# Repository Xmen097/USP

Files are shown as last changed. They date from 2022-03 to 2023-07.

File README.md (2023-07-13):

# USP
Univerzální sériový programátor pro (převážně) AVR čipy.

### Popis
Hlavním cílem projektu bylo vytvořit hardwarový výrobek, který bude reálně užitečný a výraznězjednodušší nahrávání do (převážně) AVR čipů v pouzdře DIP, bez nutnosti zapojovat cokoliv na nepájivém poli. Programátor detekuje jaký čip je do něj vložený umožňuje ho programovat ze sériové linky. Na hardwarové úrovni bylo dále implementováno i několik bonusových funkcí, jako například podpora vysokonapěťového programování, které pouze čekají na implementaci v softwaru.

Sestavené ařízení bylo otestováno na několika mikrokontrolérech, konkrétně Atmega328 a Attiny13, Attiny85 a Attiny45.

Více informací v textu maturitní práce
https://github.com/Xmen097/USP/blob/master/Maturitn%C3%AD%20pr%C3%A1ce.pdf



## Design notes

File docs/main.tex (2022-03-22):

\documentclass[11pt,a4paper,twoside,openright]{report}

\usepackage[top=25mm,bottom=25mm,right=25mm,left=30mm,head=12.5mm,foot=12.5mm]{geometry}
\let\openright=\cleardoublepage

\input{macros}

\def\NazevPrace{Univerzální sériový programátor}
\def\Trida{R8.A}
\def\AutorPrace{Petr Šícho}
\def\DatumOdevzdani{25.3.2022}

% Vedoucí práce: Jméno a příjmení s~tituly
\def\Vedouci{Bc. Emil Miler}

% Studijní program a obor
\def\StudijniProgram{studijní program}
\def\StudijniObor{studijní obor}

% Text čestného prohlášení
\def\Prohlaseni{Prohlašuji, že jsem svou práci vypracoval samostatně a použil jsem pouze prameny a literaturu
uvedené v~seznamu bibliografických záznamů. Nemám žádné námitky proti zpřístupňování této práce v~souladu se
zákonem č. 121/2000 Sb. o~právu autorském, o~právech souvisejících s~právem autorským a
o~změně některých zákonů (autorský zákon) ve znění pozdějších předpisů.}

% Text poděkování
\def\Podekovani{%
Chtěl bych poděkovat především open hardware komunitě, specificky pak Arduino komunitě, na jejíchž fórech jsem našel značné množství informací. Dále děkuji Bc. Emilovi Milerovi za pomoc při vedení této maturitní práce.
}

% Abstrakt česky
\def\Abstrakt{%
Tato maturitní práce si klade za cíl zjednodušit proces programování a nahrávání kódu do mikrokontrolérů v pouzdře DIP. Univerzální sériový programátor (USP), který v rámci této práce vznikl, je zařízení, které je schopné automaticky detekovat rozložení vývodů čipu vloženého do ZIF patice. Na základě toho rozpozná o který mikrokontrolér se jedná a uzpůsobí pro něj nahrávací obvod. Teoreticky by měl USP umět programovat všechny mikrokontroléry pracující na napětí 5 voltů a podporovat dostatečně pomalé bit-banging programovací protokoly, včetně těch, které vyžadují vysoké napětí (12V) pro resetování. Aktuálně je implementována podpora rodin ATtiny a ATmega od výrobce Atmel. Na softwarové úrovni USP pracuje na protokolu Arduino ISP.
}

% Abstrakt anglicky
\def\AbstraktEN{%
This thesis aims to simplify the process of programming and uploading code to microcontrollers in a DIP package. The Universal Serial Programmer (USP), which was created in this work, is a device that is able to automatically detect the distribution of terminals on a chip inserted into the ZIF socket. Based on this, it recognizes which microcontroller is present and adapts the programming circuit for it. Theoretically, the USP should be able to program all microcontrollers operating at 5 volts and supporting sufficiently slow bit-banging programming protocols, including those that require high voltage (12V) for reset. A support is current implemented for the ATtiny and ATmega families from the manufacturer Atmel. At a software level, the USP is working on the Arduino ISP protocol. 
}

% 3 až 5 klíčových slov
\def\KlicovaSlova{programátor, mikrokontrolér, AVR, nahrávač, USP}
% 3 až 5 klíčových slov anglicky
\def\KlicovaSlovaEN{programmer, microcontroller, AVR, uploader, USP}

\begin{document}

\include{titlepage}

% Obsah
\setcounter{tocdepth}{2}
\tableofcontents

\chapter{Teoretická část}
\pagestyle{fancy}

Existuje nepřeberné množství různých čipů a s nimi podobné množství různých rozložení vývodů, které nejsou jednotné ani u jedné velikosti a jednoho výrobce. Pro každé rozložení pinů mikrokontroléru je nutné mít externí programovací obvod. Cílem práce je sjednotit tyto programovací obvody do jednoho univerzálního, který se přizpůsobí vloženému čipu. Fungování USP lze rozdělit na dvě části - detekovat čip a následně umožnit jeho programování. 

Pro univerzální programátor není možné použít žádný dedikovaný hardware, který by zajišťoval nahrávání. Naopak je vhodné použítí univerzálních vstupních~/~výstupních pinů neboli GPIO\footnote{z anglického General-purpose input/output, tedy pin, který se umí chovat buď jako digitální vstup, nebo výstup, přičemž mezi těmito módy je možné přepínat.} pinů. I přes snahu o maximální univerzálnost není reálné docílit podpory úplně všech existujících čipů. Jako minimální požadovanou funkcionalitu jsem tedy bral podporu čipů AVR od výrobce Atmel, konkrétně pak řady ATmegy a ATtiny, které zahrnují mikrokontroléry, jež pohání známé desky Arduino. Přesto se domnívám, že vlastnosti těchto čipů, na kterých je detekce a nahrávání postaveno, budou do velké míry přenositelné i na jiné rodiny či výrobce čipů.

\section{Detekce}

Základem detekce je poznat jak velký čip je - tedy kolik má vývodů. Tím bychom mohli v prvním přiblížení detekce radikálně omezit počet potenciálních kandidátů. Při zahrnutí jen několika modelů, jednoho pro každou velikost, bychom tak měli detekci téměř hotovou. Bylo by však nutné arbitrárně stanovit tyto podporované čipy, přičemž při vložení jiného, ať třeba ze stejné rodiny, který má prohozené piny GND a VCC, by došlo pravděpodobně k jeho zničení. Naší ambicí tedy bude zjistit o čipu co nejvíce informací, díky nimž budeme schopni rozeznávat mezi co největším počtem různých čipů.

Při detekci si musíme dávat pozor, abychom náhodou mikrokontrolér nepoškodili. Ideálně bychom se chtěli držet v hodnotách, které povoluje jeho datasheet. Problém je, že to, o co se pokoušíme, není standardní zacházení s čipy a v datasheetu tak nenalezneme konkrétní povolené hodnoty a situace, kterým můžeme čip bezpečně vystavit. Z datasheetu vybraných AVR čipů \cite{attiny85, atmega328, atmega2560, attiny84} můžeme alespoň určit některé společné zásady, kterých když se budeme držet, tak minimalizujeme poškození čipu. Konkrétně se jedná o:
\begin{itemize}
	\item Nevystavovat žádný pin napětí nižšímu než $-0.5V$
	\item Nevystavovat žádný pin, kromě RESETu, napětí vyššímu než ${V}_{cc} + 0.5V$
	\item Nevystavovat RESET napětí vyššímu než $13V$
	\item Nenechat mezi žádný dvěma piny nezapojeného čipu téct nezanedbatelně velký proud po nezanedbatelně dlouhou dobu\footnote{Pro naše účely budeme považovat za zanedbatelný proud řádu mikroampér a čas mikrosekund.}
\end{itemize}
Při splnění těchto podmínek by měl být čip dostatečně chráněn obvody, které běžně slouží k ochraně před elektrostatickým výbojem (ESD). 

\subsection {Detekce velikosti a polohy \label{theory:capacitance}}

Pro detekci velikosti čipu můžeme využít toho, že každá reálná součástka, kromě svých primárních vlastností, vykazuje také elektrickou kapacitu. To bude jistě platit i pro spoje a součástky uvnitř integrovaných obvodů. Elektrická kapacita pinů jednoduchých CMOS\footnote{Complementary metal-oxide semiconductor; technologie výroby integrovaných obvodů.} čipů \cite{multiplexer, switch2, switch1} se pohybuje v jednotách pikofaradů. Není mi znám žádný způsob přímého měření elektrické kapacity, budeme tedy muset provést měření nepřímé a dostatečně přesné. Jednou z možností je kapacitor pomalu nabíjet nebo vybíjet a měřit čas, který k tomu budeme potřebovat. Zkusíme odhadnout jak přesné takové měření bude s pomocí rovnice definující energii elektrického kondenzátoru \begin{equation} E = \frac{1}{2}CU^2 \end{equation}
Budeme-li kapacitor nabíjet napětím $U$ a proudem $I$ po dobu $t$, můžeme psát
\begin{equation} {W}_{max} = U \cdot I \cdot t \end{equation} 
Jedná se o horní odhad vykonané práce, která počítá s nulovým odporem a nulovým elektrickým potenciálem kapacitoru. Reálná energie předaná kapacitoru bude nižší, což nám však nevadí. Úpravou těchto dvou vztahů můžeme vyvodit úměrnost
\begin{equation} C \simeq t / R \end{equation}

Zjistili jsme, že kapacita je přímo úměrná času, po který jsme kapacitor nabíjeli, a nepřímo úměrná odporu, přes který jsme nabíjeli.\footnote{Ke stejnému výsledku bychom došli i použitím rozměrové analýzy.} Čas budeme schopni měřit velice přesně\footnote{Přesnost měření času je omezena frekvencí oscilátoru řídícího mikrokontroléru, běžně se pohybuje v desítkách megahertzů.}, řádově v mikrosekundnách ($10^{-6} s $). Řekněme, že pin čipu má kapacitu $10 pF = 10^{-11} F$. Dosazením do vztahu (1.3) zjistíme, že k jejímu změření budeme potřebovat nabíjecí odpor o velikosti $100 k\Omega$. To nebude problém, měření vypadá proveditelně.

Díky schopnosti změřit kapacitu na každém z pinů socketu zjistíme nejenom jak velký čip je, ale zároveň i kde v socketu je vložen. Není tedy nutné nijak specifikovat na jakou pozici v socketu má být čip pro nahrávání vložen.

\subsection {Detekce speciálních pinů}

Každý mikrokontrolér má kromě vstupních~/~výstupních pinů i speciální piny, které plní nějakou zvláštní funkci. Například je to RESET pin, napájecí piny (GND a VCC) nebo piny hodin (XTAL). Tyto piny by mohly vykazovat rozdílné elektrické vlastnosti a možná i rozdílnou kapacitu. Vzhledem k tomu, že napájecí piny jsou vnitřně připojené k všemožným součástem mikrokontroléru, lze hlavně u těchto pinů očekávat vyšší kapacitu. Tu bychom při dostatečně přesném měření kapacity detekovat a rozpoznat tak polohu napájecích pinů.

\subsection {Rozpoznání VCC od GND\label{VCCvsGND}}

Při špatném rozpoznání vloženého mikrokontroléru může největší poškození způsobit převrácení pinů GND a VCC. Abychom se tohoto rizika vyvarovali, je nutné rozpoznávat s jistotou VCC od GND. Tím zároveň obecně snížíme šanci na špatné rozpoznání čipu.

Využijeme ochranných diod, které jsou připojeny ke každému IO pinu mikrokontroléru, jak ukazuje obrázek \ref{fig:pin_diagram}. Povšimněme si, že dioda spojující pin s GND směřuje opačně, než dioda spojující pin s VCC. Díky tomu bychom měli být schopni rozpoznat, zda je určitý pin GND či VCC.

\begin{figure}[ht!]
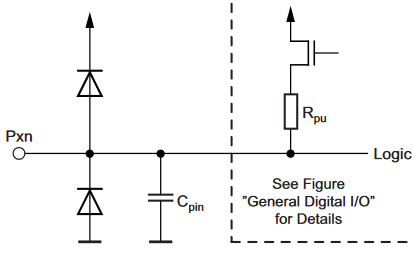
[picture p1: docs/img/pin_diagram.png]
  
  \centering
  \caption{Schéma vnitřního zapojení IO pinu mikrokontroléru \cite[str.~58]{atmega328}.}
  \label{fig:pin_diagram}
\end{figure}

Pin GND můžeme detekovat následovně. Budeme znát úbytek napětí na diodě mezi pinem a GND $U_d$. Přivedeme-li na pin GND napětí $U$ převyšující $U_d$, měli bychom na všech IO pinech detekovat napětí $U-U_d$. Z bezpečnostních důvodů by napětí $U$ by mělo být co nejmenší možné, ideálně $U<0.5V$. Napětí přivedeme přes dostatečně velký odpor tak, aby mikrokontrolérem a diodou tekl co nejmenší proud. S malým procházejícím proudem budeme mít také menší úbytek napětí na diodě (menší, než běžně udávaných $\sim0.7V$)

Obdobným způsobem je možné detekovat pin VCC. Stačí na libovolný (nebo lépe postupně na všechny) IO pin přivést napětí $U$ a na pinu VCC by se nám vždy mělo ukázat napětí $U-U_d$.

\subsection {Závěr}

S touto výbavou bychom měli být schopni dostatečně detailně rozpoznat mikrokontroléry ATmega a ATtiny. Díky rozpoznáním GND a VCC budeme schopni čip bezpečně napájet. Nebude pak problém, kdybychom chtěli rozšířit podporované čipy a vyskytly by se nám dva čipy, které mají na stejných místech GND a VCC, ale na různých místech piny potřebné pro nahrávání. V této situaci bychom postupně vyzkoušeli různá rozložení nahrávacích pinů, až bychom našli to správné.

\section {Nahrávání}

Po detekování čipu nám už zbývá pouze do něj nahrát. Vzhledem k tomu, že přesně nevíme jaké rozložení pinů bude čip mít, musíme použít tzv. bit-banging\footnote{Softwarová implementace určitého protokolu, která přímo generuje protokolem specifikovaný signál, bez použití specializovaného hardwaru.}. Díky tomu se nemusíme při stavbě hardwaru nahrávače omezovat na určité čipy, ale budeme schopni teoreticky obsluhovat všechny čipy, které nevyžadují příliš velké komunikační rychlosti\footnote{Maximální rychlost komunikace je tím, jak rychle jsme schopni zpracovávat odchozí a příchozí data.} a existuje pro ně bit-banging implementace nahrávání. Nebude tak ani obtížné obměňovat nahrávací protokoly pro různé čipy nebo situace.

Komplikací může být, že některé nahrávací protokoly vyžadují použití vyššího napětí. U AVR čipů jde konkrétně o protokoly HVSP (high voltage serial programming) a HVPP (high voltage parallel programming), které se hodí při určitém nastavení mikrokontroléru, kdy není možné standardní programování.\footnote{Jde např. o situace kdy je vypnuté resetování pomocí RESET pinu, protože ho chceme použít na jinou funkci.} Vysokým napětím je v obou případech myšleno 12 voltů \cite{AVRprog}. Vzhledem k tomu, že ve valné většině případů lze programovat mikrokontrolér bez použití vysokého napětí, bral jsem jeho dostupnost spíše jako bonus než nutný požadavek. High-voltage programováním se tedy budeme zabývat pouze z hardwarového hlediska.

\section {Shrnutí požadovaných funkcí\label{pinFunc}}

V této sekci si shrneme funkce, které budeme potřebovat pro úspěšnou detekci a nahrávání do čipů. Těmito funkcemi by měl disponovat každý z pinů socketu, neboť nevíme, kde se zrovna čip ocitne. Některé funkce budou komplexní (přečti kapacitu připojenou k pinu), u jiných se bude jednat o nějaký elementární stav (připojení k zemi/5V). 

\begin{enumerate}
\item \textbf{5V s proudem >20 mA} je potřeba pro napájení čipu. Proud 20 mA by měl stačit pro napájení AVR čipů \cite{attiny85, atmega328}. Některé větší čipy za určitých okolností mohou mít spotřebu větší než 20 mA, ale mají také více separátních napájecích pinů, mezi které se proud rozloží \cite[str.~286-323]{atmega32}.
\item \textbf{0V (GND) s proudem >20 mA} je potřeba též pro napájení čipu. 
\item \textbf{5V s libovolně malým proudem} reprezentuje logický stav 1 při komunikaci, odebíraný proud během komunikace bude zanedbatelný.
\item \textbf{0V (GND) s libovolně malým proudem} reprezentuje logický stav 0 při komunikaci.
\item \textbf{Čtení digitální hodnoty} pro čtení odpovědi čipu při nahrávání; standardní funkce GPIO pinů.
\item \textbf{Přečtení kapacity} pro detekci čipu.
\item \textbf{Napětí přibližně 0.4-0.5V} je potřeba pro rozpoznání GND a VCC, viz sekce \ref{VCCvsGND}.
\item \textbf{Přečtení napětí na pinu} je také potřeba pro rozpoznání GND a VCC.
\item \textbf{12V} bude potřeba pokud budeme chtít high-voltage programování.
\item \textbf{Nepřipojeno} k ničemu. Piny, které nevyužíváme k jiné funkci, by se měly chovat tak, jako kdyby nebyly k ničemu připojené.
\end{enumerate}

%%% IMPLEMENTACE

\chapter{Implementace}

Implementace projektu měla dvě fáze. Nejprve bylo potřeba navrhnout hardwarovou část - vymyslet a vyzkoušet jednotlivé části obvodu tak, aby plnily požadované funkce. Poté bylo potřeba všechny spojit do jednoho celku, který se vyrobí jako plošný spoj. Po osazení plošného spoje součástkami a otestování základní funkčnosti následoval vývoj softwaru. Jako první probíhala implementace low-level komunikace s jednotlivými součástkami, pak přišly na řadu high-level funkce detekce. 

Pojďme si nyní jednotlivé fáze rozebrat detailněji.

\section {Hardware}

Převážná část práce na hardwaru probíhala s pomocí nepájivého pole, na kterém jsem postupně testoval jednotlivé ideje uvedené v teoretické části práce. V následujících sekcích si rozebereme jaké součástky byly použity a jak se pomocí nich implementují požadované funkce ze sekce \ref{pinFunc}.

\subsection {Vkládání čipu}

Jako patici, do které se bude vkládat čip k programování, jsem zvolil ZIF (zero insertion force) socket. Jak již jméno napovídá, pro vložení čipu do patice není nutné užití síly. Stačí čip položit na patici a pomocí páčky na straně patice čip zajistit, čímž vznikne spolehlivý kontakt s piny čipu. Nehrozí tak ohnutí nožiček čipu a jeho vložení i vyndání je velmi rychlé. Nevýhodou ZIF socketu je o trochu vyšší pořizovací cena a větší velikost, ale i přesto se v našem případě určitě vyplatí. Konkrétně jsem zvolil patici se 40 piny (dvaceti na každé straně), která by měla postačovat pro naprostou většinu DIP\footnote{Dual in-line package; pouzdro s THT piny s roztečí 2.54mm.} pouzder. Patice podporuje vložení jak úzké (0.3''), tak široké (0.6'') varianty DIP.

\subsection {Řídící mikroprocesor}

Je potřeba zvolit mikroprocesor, který bude ovládat celý nahrávač. Volil jsem mezi mikrokontroléry AVR, s kterými jsem nejvíce obeznámen a které také umí jednoduše komunikovat s Arduino IDE. Zásadní otázkou je kolik budeme potřebovat GPIO pinů k ovládání USP. Určitě bude potřeba jeden pin pro každý pin ZIF patice, tedy minimálně 40 pinů. Další desítky pinů budou potřeba pro ovládaní komponent a součástek, o kterých se budu detailněji zmiňovat v dalších sekcích. Teoreticky by bylo možné přidat další piny pomocí shift registrerů či IO expanderů. Tím by však utrpěla rychlost komunikace a vzrostla by komplexita desky a tím i prostor pro chyby. Rozhodl jsem se tedy pro jeden co největší čip, mikrokontrolér ATmega2560 v pozdře TQFP100, který má 84 GPIO pinů \cite{atmega2560}.

Nejprve jsem plánoval, že bych využil dostupných schémat Arduino desek a v upravené podobě je přímo zakomponoval do desky nahrávače. To by umožnilo využít řídící čip bez omezení. Na druhou stranu by tím extrémně vzrostla komplexita desky a také celková cena. Nakonec jsem se tedy rozhodl programátor vyvinout jako shield (nasazovací desku) na Arduino Mega s mikroprocesorem ATmega2560. Nevýhodou tohoto postupu může být snad jen to, že Arduino mega nám dává k dispozici pouze 70 z 84 GPIO pinů, ale i to by mělo pro tento projekt stačit \cite{ArduinoMega}.

\subsection {Základní funkcionalita pinů}

Nyní přichází na řadu implementace požadovaných funkcí popsaných v sekci \ref{pinFunc}. Jenom tím, že ke každému pinu ZIF socketu bude připojený GPIO pin, zajistíme funkce 3, 4, 5, které GPIO piny zvládají nativně. Funkce 1 a 2, které vyžadují minimální proud 20 mA, také s trochou opatrnosti zvládneme. Digitální piny ATmegy2560 dokáží dodávat maximální proud 40 mA \cite[str.~355-356]{atmega2560}. Musíme tedy jen dát pozor na to, aby další součástky, které budou zapojeny mezi GPIO pinem a pinem ZIF socketu neměly příliš velký odpor nebo nevyžadovaly více omezený protékající proud.

Desátý požadavek vyžaduje trochu zamyšlení. Pin určitě nebude možné fyzicky odpojit, to bychom museli provést manuálně. Budeme tedy alespoň chtít minimalizovat proud, který může skrz tento \lq odpojený\rq   pin téct. Když nastavíme GPIO pin jako vstupní, bude ve stavu s tzv. vysokou impedancí, tedy poteče jím malý proud. Datasheet specifikuje maximální proud jako $1 \mu  A$, typický proud lze očekávat výrazně menší \cite[str.~355]{atmega2560}. Odpojení si navíc můžeme pojistit použitím analogového přepínače, u kterého je udáván maximální proud $100nA$ a typický $0.05nA$ \cite[str.~3]{switch1}.

\subsection {Zapojení multiplexerů}

Implementaci funkcí 6, 7, 8 a 9 si zjednodušíme pozorováním, že v jednu chvíli bude daná funkce potřebná pouze na jednom pinu. Nemusíme ji tedy implementovat 40x, ale můžeme použít multiplexery k spojení určitého pinu s něčím, co nám funkci zajistí. Napětí na pinu budeme číst pomocí ADC\footnote{Analogově digitální převodník; zařízení, které převede analogový signál (napětí) v určitém rozsahu na digitální tvar s určitým počtem bitů, v našem případě se jedná o převodník 10-bitový.} převodníku. Atmega2560 disponuje jedním ADC převodníkem, který je ale vnitřně multiplexován na 16 GPIO pinů. Pomocí dalších multiplexerů rozšíříme tuto funkcionalitu na všech 40 pinů.

%Pro zajištění správného přečtení napětí nemůžeme nechat ADC převodník tzv. floating, tedy nepřipojený k ničemu, kdy vrací víceméně náhodné hodnoty. Všech 5 ADC pinů, které využíváme, je tedy připojeno rezistorem $1M\Omega$ k zemi. Takto vysokou hodnotu rezistoru jsem volil, aby se nezkreslily výsledky měření kapacity.

Multiplexery se standardně vyrábí s $2^n$ kanály, které se ovládají pomocí $n$ pinů. Zvolil jsem 8 kanálové multiplexery \cite{multiplexer}, tedy s 3 ovládacími piny. Pro obsluhu 40 pinů jich bude potřeba celkem 5. Multiplexery jsou připojeny k pinům ZIF socketu způsobem znázorněným na obrázku \ref{fig:mux_diagram}.

\begin{figure}[ht!]
  
  \centering
  \caption{Schéma zapojení mulitplexerů k pinům ZIF patice.}
  \label{fig:mux_diagram}
\end{figure}

Díky tomuto způsobu zapojení budeme schopni odhalit závadu na multiplexeru při rozpoznávání čipu, neboť i nejmenší mikrokontrolér, který má pouzdro DIP8 se 4 piny na každé straně, bude mít vždycky alespoň dva piny v různých multiplexerech. Nestane se tedy, že by kvůli závadě na jednom multiplexeru (ta může být způsobená i třeba dotekem uživatele, kterým se zvýší kapacita) byl čip chybně rozpoznán.

\subsection {Napěťový dělič \label{voltage_divider}}

Napětí 0.4-0.5V, jak si žádá sedmý požadavek, vytvoříme pomocí napěťového děliče. Zde se nám budou hodit již výše zmíněné multiplexery. Dělič napětí bude totiž právě mezi GPIO pinem a multiplexovaným pinem. Na každém GPIO pinu je možné zapnout tzv. pullup rezistor, který pin připojí přes odpor s přibližnou velikostí $30-40k\Omega$\footnote{Datasheet udává, že odpor bude vždy větší než $20k\Omega$ a menší než $50k\Omega$. Vzhledem k tomu, že tyto hodnoty jsou pro teplotní rozmezí od -55°C do 125°C můžeme konstatovat, že při pokojové teplotě bude odpor přibližně mezi $30-40k\Omega$.} k 5 voltům. Kýžené napětí přibližně půl voltu vytvoříme dalším rezistorem s velikostí $3.3k\Omega$\footnote{Chceme dělič napětí přibližně 1:10, hodnotu odporu jsem zvolil o něco nižší, protože i samotný multiplexer bude mít určitý odpor (asi 100 ohmů).} k zemi. Zapojení děliče napětí na pinu je vidět na obrázku \ref{fig:voltage_divider}

\begin{figure}[ht!]
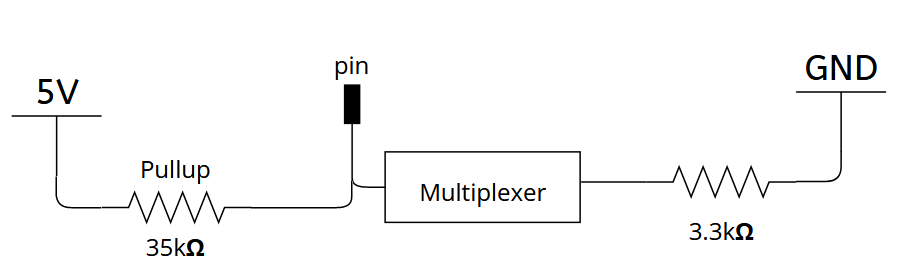
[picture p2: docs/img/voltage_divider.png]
  
  \centering
  \caption{Schéma děliče napětí.}
  \label{fig:voltage_divider}
\end{figure}

\subsection{Měření kapacity}

Kapacitu lze měřit, jak jsme vyvodili v sekci \ref{theory:capacitance}, pomocí pomalého nabíjení - tedy nabíjení přes dostatečně velký rezistor. Vypočítali jsme, že by se nám hodil rezistor s odporem $100k\Omega$. Připojovat takový odpor k pinům by si však vyžádalo dalších multiplexerů nebo switchů. Můžeme ale využít stejných pullup rezistorů, které využíváme pro napěťový dělič. Ty jsou o něco menší a mohlo by se stát, že kapacitor nabijeme příliš rychle. Můžeme ale využít ADC převodníku, který máme multiplexovaný k pinům. Původně jsme chtěli měřit čas, za který nabijeme plně kapacitor, což bychom zjišťovali pomocí digitálního vstupu GPIO pinů. Můžeme to ale provést i opačně. Kapacitor budeme nabíjet nějaký konstantní čas, a poté pomocí ADC převodníku zjistíme napětí na kapacitoru. Čím vyšší napětí bude, tím více jsme kapacitor nabili a tím je tedy kapacitor menší. Opačně by šlo i kapacitor plně nabít a poté ho nechat samovolně vybíjet. Počkáme konstantní čas a opět pomocí ADC převodníku zjistíme, jak moc se vybil. 

Při testování se ukázalo, že pro měření kapacity se nám velmi hodí i dělič napětí, podrobněji viz sekce \ref{software:capacitance}

\subsection {Napětí 12 voltů\label{12v}}

Poslední funkcionalitou, kterou nám zbývá implementovat je dostupnost napětí 12 voltů. To můžeme na pin pouštět pomocí stejných multiplexerů, které využíváme k připojení ADC převodníku. Stačí pomocí switche CD4066B \cite{switch2} přepínat zdroj multiplexeru mezi 12 volty a ADC převodníkem. Zapojení tohoto obvodu pro multiplexer 1 a 2 je vyobrazeno v příloze  \ref{appendix:mux_input_control}. Od použitého switche nepožadujeme žádné zvýšené nároky ohledně proudu, pro HVSP i HVPP nám stačí malý proud. Problém je, že náš řídící mikrokontrolér, ale ani většina dobře dostupných multiplexerů, nepodporuje vyšší napětí než 5 voltů. S trochou snahy se dají najít i multiplexery podporující 12 voltů. Řídíci čip, jehož piny odolají napětí 12 voltů, ale prakticky není možné najít. Budeme proto muset piny řídíciho mikrokontroléru odpojit předtím, než připojíme 12 voltů. K tomu využijeme analogové switche MC14066B \cite{switch1}. Vzhledem k tomu, že přes tyto switche budeme mimo jiné napájet čip, který budeme chtít programovat, musí podporovat průtok proudu alespoň $20mA$.\footnote{Z tohoto důvodu se použitý switch liší od switchů \cite{switch2}, které používáme u zdroje multiplexeru.} 

Každý switch má 4 kanály, které dokáže přepínat pomocí 4 ovládacích pinů. Není však možné ani potřebné ovládat každý z těchto pinů individuálně, na to bychom totiž spotřebovali dalších 40 pinů. Šlo by pomocí tranzistorů a odporů detekovat zvýšené napětí a přepnout ovládací pin switche. To by však vyžadovalo značné množstí externích komponent - na každý pin jeden tranzistor a několik odporů. Lepší řešení je založené na faktu, že 12 voltů bude vždy připojené na pinu, který je multiplexován. Toho využijeme a přidáme další multiplexer, který bude mít stejně zapojené ovládací piny jako první multiplexer. Bude fungovat tak, že vypne kanál, který obsluhuje pin, ke kterému je multiplexováno. Tímto zajistíme přepínání s použitím pouze jediného pinu, který bude sloužit k potlačení této funkcionality, která by nám rozbila napětový dělič a další funkce. Zjednodušené schéma tohoto systému pro 8 pinů ZIF patice je znázorněno na obrázku \ref{fig:simplified_pin_switches}. Tento obvod je na USP celkem 5 krát - pro každých 8 pinů, a to podle stejné schématu jako zapojení původních multiplexerů (obrázek \ref{fig:mux_diagram}). Kompletní zapojení toho obvodu je dostupné jako příloha \ref{appendix:pin_switches}.

\begin{figure}[ht!]
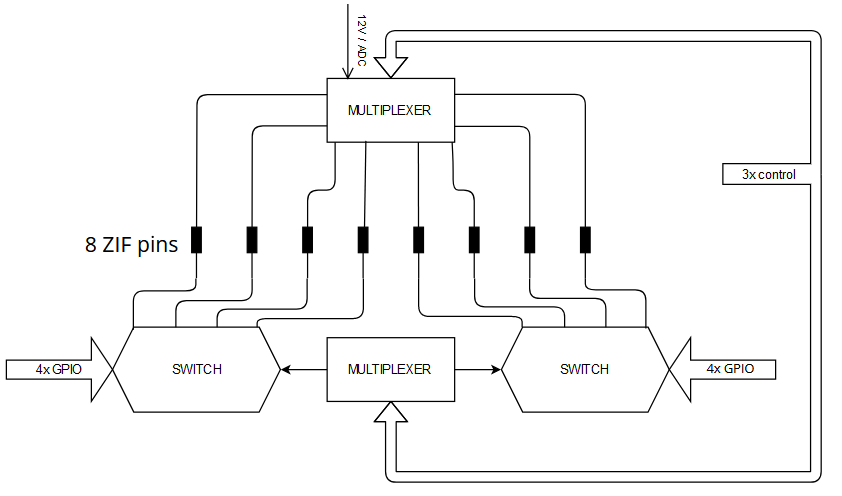
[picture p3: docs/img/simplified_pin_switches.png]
  
  \centering
  \caption{Zjednodušené schéma obvodu připojeného k 8 pinům ZIF patice}
  \label{fig:simplified_pin_switches}
\end{figure}

Další komplikací spojenou s vyšším napětím je, že multiplexery a switche potřebují být ovládané tímto napětím. Nestačí tedy již připojit na ovládací pin multiplexeru/switche GPIO pin řídícího mikrokontroléru, ale je nutné použít tranzistor a pullup/pulldown\footnote{V závislosti na tom v jakém výchozím stavu chceme, aby byl ovládací pin; ve většině případu se bude jednat o pulldown rezistor.} rezistor.

Poslední věcí, kterou musíme vyřešit, je kde získat napětí 12 voltů. Jednou možností by bylo zapojit do USP přímo toto napětí z externího zdroje, to by ale výrazně ztížilo jeho použití. Rozhodl jsem se proto přímo do USP zabudovat step-up převodník, který nám vytvoří napětí 12V. Obvod step-up převodníku byl navržen podle datasheetu regulátoru MC34063A \cite{step-up}. Celé zapojení obvodu převodníku je zobrazeno v příloze \ref{appendix:boost_converter}.

\subsection {Dodatečný hardware}

Krom výše uvedených součástek a obvodů, které slouží k zajištění detekce nebo nahrávání, je USP vybaven také 0.91'' OLED displejem a čtyřmi tlačítky. To umožní tvorbu uživatelského rozhraní pro jednodušší ovládání programátoru. OLED displej je také užitečným nástrojem pro debugování. Dále jsou pak na programátoru tři LED - modrá, zelená a červená, které slouží pro optickou signalizaci stavu programátoru.

\subsection {Využití pinů}

Nakonec se ukázalo, že 70 pinů není až zase tolik a bylo nutné s nimi trochu šetřit. Následovat bude krátký přehled toho, k čemu bylo použito kolik pinů a případně jakým způsobem byly piny uspořeny.

\begin {itemize}
\item \textbf{40 pinů} je nutných k obsloužení všech pinů na ZIF patici.
\item \textbf{5 pinů s podporou ADC} je připojeno k pěti multiplexerům.
\item \textbf{3 piny} jsou použity pro sdílenou kontrolu multiplexerů na právé straně ZIF patice (1, 2 a 3). \footnotemark{}
\item \textbf{3 piny} jsou použity pro sdílenou kontrolu multiplexerů na levé straně ZIF patice (4 a 5). \footnotemark[\value{footnote}]
\item \textbf{5 pinů} ovládá jestli je každý z pěti multiplexerů připojen k 12 voltům nebo ADC převodníku.
\item \textbf{1 pin} ovládá zda switche odpojují piny, na které je právě multiplexováno, jak je popsáno v sekci \ref{12v}.
\footnotetext{Pro všechny funkce kromě rozpoznání VCC a GND (sekce \ref{VCCvsGND}) nám stačí vždy jen jeden pin připojený k multiplexeru, ostatní multiplexery můžeme ignorovat. Pro rozpoznání VCC a GND budeme potřebovat dva multiplexery, jeden pro vytvoření malého napětí a druhý pro čtení ostatních pinů. K tomu nám ale postačí nezávisle ovládat multiplexery na jiných stranách ZIF patice, neboť díky rozložení multiplexerů podle obrázku \ref{fig:mux_diagram} bude mít i nejmenší možný čip alespoň dva piny na různých stranách.}
\item \textbf{2 piny} jsou použity pro display.
\item \textbf{4 piny} jsou využívány tlačítky.
\item \textbf{3 piny} ovládají LEDky.
\item \textbf{2 piny} jsou potřeba pro sériovou komunikaci s počítačem.
\item \textbf{zbylé 2 piny} jsou vyvedeny do headeru.
\end {itemize}

Celkem je tedy využito všech 70 dostupných pinů.

\subsection {Plošný spoj}

Po otestování částí některých výše zmíněných obvodů na nepájivém poli bylo potřeba vytvořit návrh desky plošného spoje. Rozhodl jsem se rovnou pro 4-vrstvý plošný spoj, vzhledem k tomu, že jsem plánoval umístit co nejvíce součástek na co nejmenší plochu a vrchní vrstva je tak prakticky celá pokryta ploškami pro kontakty součástek. Prostřední dvě vrstvy jsou udělány jako tzv. plane, kde většina vrstvy zabírá jeden signál, zde konkrétně země a napájení, a slouží pro snížení rušení na desce. Hotového zapojení plošného spoje je k nahlédnutí v příloze \ref{appendix:board}.

%Plošný jsou jsem si nechal vyrobit a osadit SMD součástkami u nejmenované čínské firmy. Hlavní výhodou objednání z Číny je řádově menší cena, než u ostatních výrobců, problémem na druhou stranu může být, že čínané mají často vlastní kopie součástek a jejich datasheety nejsou přeložené do angličtiny. Většinou jsou k nalezení anglické datasheety prakticky totožných součástek jiných výrobců. Po výrobení plošného spoje jsem začal zjišťovat na co vše jsem při návrhu zapomenul a co nefunguje. Naštěstí nic z toho nebylo kritické a bylo možné všechny nedostatky opravit.

%%% SOFTWARE

\pagebreak
\section {Software}

Přestože bylo cílem projektu vytvořit co nejlepší hardwarový výrobek, je jeho nedílnou součástí i software nutný k zprovoznění tohoto hardwaru. Nicméně ne všechny funkce implementované na hardwarové úrovni jsou využity ze strany softwaru. 

\subsection{Princip fungování}

Po zapnutí USP detekuje vložení čipu, který následně identifikuje a data o něm předá nahrávači (více o něm v sekci \ref{software:uploader}). Nahrávač pak vykonává příkazy, které dostane po sériové lince a programuje vložený čip, dokud uživatel nezmáčkne resetovací tlačítko. Princip fungování konkrétně zachycuje obrázek \ref{fig:app_diagram}. 

\begin{figure}[ht!]
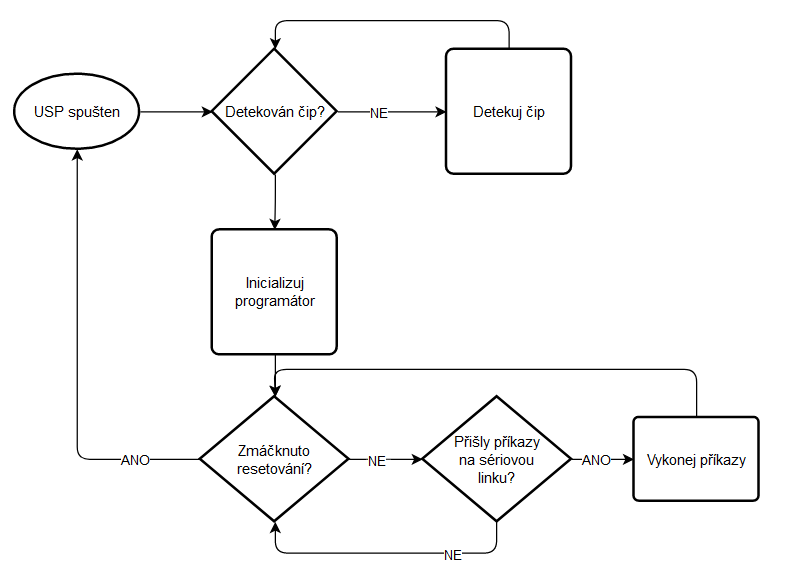
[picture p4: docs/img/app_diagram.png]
  
  \centering
  \caption{Diagram USP}
  \label{fig:app_diagram}
\end{figure}

\subsection {Nízkoúrovňové funkce}

Jako první bylo potřeba implementovat funkce pro ovládání hardwaru - konkrétně multiplexerů, OLED displeje a tlačítek. U tlačítek stačilo implementovat tzv. debouncing, tedy brát tlačítko jako stisknuté až tehdy, když se jeho stav po nějakou dobu nemění.

Pro práci s displejem jsem použil knihovnu od Adafruitu pro ovladač SSD1306, kterým je displej vybaven. Pro převod obrázků a grafik na displej jsem využil aplikaci image2cpp \cite{image2cpp}. Na displeji jsou implementovány převážně debugovací funkce, které se však mohou hodit i během provozu zařízení. Není totiž vyloučené, že měření, která bylo potřeba nakalibrovat\footnote{Měření kapacity je kalibrované pomocí aditivní a multiplikativní konstanty, které byly nalezeny experimentálně. Bez těchto úprav se kapacita na pinech výrazně lišila, pravděpodobně z důvodu rozdílné délky spojů na PCB, případně jejich vystavení působení jiných komponent.}, se budou v určitých situacích chovat trochu jinak a bude nutné je kalibrovat znovu. Z tohoto důvodu jsou kalibrační data uložena v paměti EEPROM, aby je bylo možné měnit i bez flashování.

Pro zprovoznění multiplexerů jsem použil návrhový vzor Composite, kdy každý z pěti multiplexerů je instancí třídy, která obstarává vnitřní mapování jeho ovládacích pinů na výstup a další nastavení. Všechny multiplexery jsou pak společně ovládány pomocí jiné třídy, která pozná, který multiplexer má použít.

\subsection {Interface \label{software:capacitance}}

Interface funguje jako prostředník mezi nízkoúrovňovými hardwarovými funkcemi a detektorem, kterým se bude zabývat následující sekce. Poskytuje funkce změření kapacity či napětí na pinu, připojení napětí 0.5 voltu a další.

Měření kapacity bylo implementování s přesností, která umožňuje rozpoznání polohy speciálních pinů. Prakticky měření probíhá tak, že pin nabíjíme pomocí napětí 0.5 voltů po dobu 5 mikrosekund\footnote{Tato doba při testování dávala nejlepší výsledky.}. Pak nabíjet přestaneme a změříme napětí, které na pinu je. Samotné změření napětí trvá nějaký čas, během kterého se pin stihne částečně vybít. Změřené napětí je tedy zčásti dáno rychlostí nabíjení i rychlostí vybíjení. Tento způsob měření ukázal, že piny GND a VCC mají prakticky dvojnásobnou měrnou kapacitu než normální piny. Pin RESET je také zajímavý. U některých čipů se z pohledu kapacity chová jako kdyby tam vůbec nebyl. U jiných čipů má naopak kapacitu výrazně vyšší než normální piny. V obou situacích jsme schopni pin RESET rozpoznat jako speciální pin.

\subsection {Detektor}

Detektor implementuje vysokoúrovňovou detekci čipů. Jeho fungování je znázorněno na obrázku \ref{fig:detector}. 

\begin{figure}
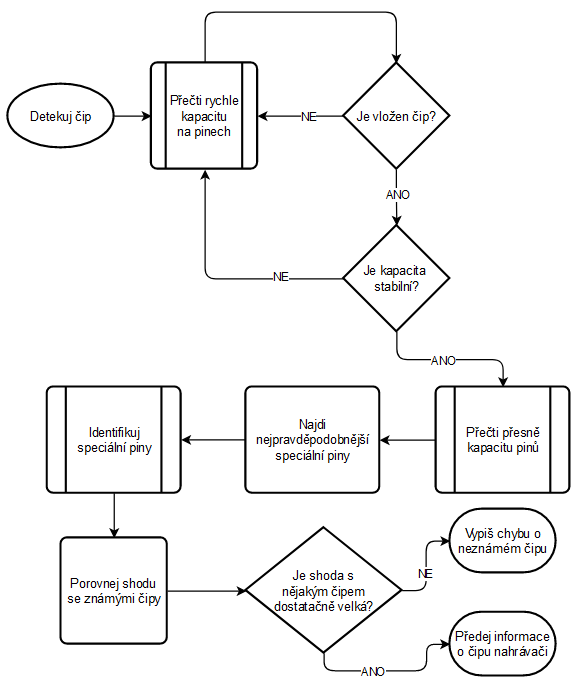
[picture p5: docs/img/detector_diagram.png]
  
  \centering
  \caption{Diagram fungování detektoru. Dvojité obdélníky značí funkce, které interagují s hardwarem}
  \label{fig:detector}
\end{figure}

Jednou z důležitých funkcí je detekce speciálních pinů. Pro každý pin vloženého čipu vyčíslíme, jak moc se relativně odlišuje od průměrné kapacity pinů na daném čipu. Toto číslo budeme přeneseně brát jako pravděpodobnost, že pin je speciálním pinem. Pět pinů\footnote{Nejvyšší počet speciálních pinů, který může AR čip o maximální podporované velikosti, je 5, včetně RESETu, ale teoreticky ani čip s více speciálními piny nebude problém detekovat, neboť i s pomocí pěti pinů bychom ho měli s jistotou určit.} s největší pravděpodobností vybereme a budeme je dále identifikovat, jak zachycuje obrázek \ref{fig:detect_special}.
Vzhledem k zjištěním při měření kapacity popsaných v sekci \ref{software:capacitance} by se mělo jednat, s danou pravděpodobností, o některý ze speciálních pinů - tedy buď GND, VCC nebo RESET.

\begin{figure}
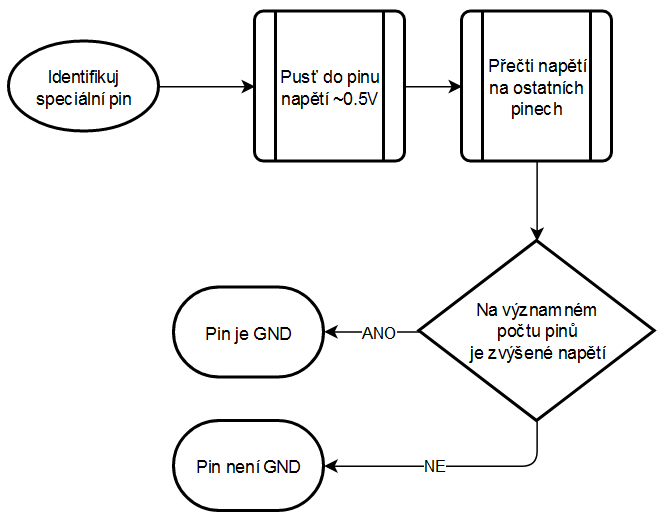
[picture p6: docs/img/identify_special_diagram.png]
  
  \centering
  \caption{Diagram identifikace speciálních pinů}
  \label{fig:detect_special}
\end{figure}

Cílem identifikace je rozpoznat, jestli je speciální pin GND. Ke pět nejpravděpodobnějším speciálním pinům, které jsme vybrali, si doplníme informaci jestli jsou pinem GND. Pokud pin není GND, jedná se buď o VCC, RESET, nebo o pin, který byl chybně detekován jako speciální (v takovém případě by jeho pravděpodobnost, a tedy i vliv na výslednou volbu čipu, měla být minimální).

Nakonec budeme iterovat přes všechny podporované čipy dané velikosti a pro obě možná otočení čipu zjistíme, jestli jeho speciální piny sedí se speciálními piny, které jsme detekovali. Výsledná shoda čipu je součet pravděpodobností těchto shodných speciálních pinů. Nejpravděpodobnější čip, který překonal stanovenou minimální shodu, je prohlášen za identifikovaný a informace o něm jsou předány dále.

\subsection {Nahrávač \label{software:uploader}}

Díky detektoru teď víme, jaký čip je vložen do patice, na jaké je pozici a jak je orientovaný. Víme tedy také, kde jsou umístěny piny, které potřebujeme pro nahrávání. Tyto informace již tedy stačí předat nahrávači. Pro zjednodušení jsem využil již implementovaný nahrávač, Arduino ISP, který je distribuovaný s Arduino IDE. Tento nahrávač jsem zvolil mimo jiné proto, že ho lze snadno ovládat právě z Arduino IDE a při použití USP uživatelem tedy nebude nutné nic instalovat ani upravovat.

Do Arduino ISP jsem doimplementoval softwarový oscilátor pomocí hardwarového časovače zabudovaného v čipu ATmega2560 \cite{atmega2560}. Díky tomu je možné programovat i čipy, které vyžadují externí oscilátor.

Implementace nahrávače je udělaná tak, aby ho v případě potřeby bylo možné snadno vyměnit za jiný. To bude nutné třeba pro přidání podpory HVSP či HVPP, neboť tyto protokoly Arduino ISP nepodporuje.

\chapter{Technická dokumentace}

\section {Použití}

Univerzální sériový programátor nevyžaduje instalaci žádného dalšího programu pro použití. Z vnějšího pohledu se chová stejně jako standardní Arduino ISP, které je široce podporované. Po zapojení do počítače přes USB type-B port, kterým je Arduino Mega vybaveno, může chvíli (několik sekund) trvat, než se USP inicializuje a zahájí komunikaci s počítačem přes sériový port\footnote{Ke komunikaci je nutné mít ovladače, ty se ale nainstalují samy při instalaci Arduina IDE, AVRDUDE nebo podobných programů.}. Poté, co se na obrazovce USP objeví nápis \lq Ready\rq ,  je USP připraven k vložení čipu. Ten může být vložen s libovolnou orientací a na libovolné místo. Aktuální verze USP podporuje prakticky všechny čipy řad Atmega a ATtiny v provedení DIP.\footnote{Fyzicky jsem však testoval jen dva různé čipy ATtiny a jeden ATmega, takže je možné, že pro určité specifické čipy bude potřeba upravit parametry v kódu a ten flashovat do USP, více o tom v sekci \ref{selfupload}.} 

Ihned po vložení čipu a jeho zajištění páčkou probíhá detekování. Během tohoto procesu se programátoru nedotýkejte, mohlo by to způsobit špatnou detekci čipu. Po detekování se na displeji ukáže jméno detekovaného čipu.\footnote{Jméno na displeji se může lišit od reálného použitého čipu, neboť existuje mnoho variant čipů se stejným rozložením. Na displeji je zobrazeno jméno nejznámnějšího čipu s daným rozložením nebo čipu s největší pamětí.} V této chvíli je již možné do čipu nahrávat stejným způsobem jako do normálního zařízení Arduino ISP. Možné způsoby nahrávání do čipů přes USP si rozebereme v následujích sekcích.

Po vyndání čipu je možné stiskem libovolného tlačítka resetovat USP do původního stavu a připravit ho na další čip, který je možné vložit poté, co se na displeji objeví \lq Ready\rq .

\subsection {Použití s Arduino IDE}

Použití s Arduino IDE je pravděpodobně nejjednodušší. Jako příklad řekněme, že chceme nahrát program do čipu Atmega328P, který mimo jiné pohání Arduino Uno. Prvním krokem je zvolit Arduino ISP jako programátor pod Nástroje>Programátor>Arduino as ISP a zvolit Port do kterého je USP připojen. V nabídce portů se bude USP ukazovat pod jménem Arduino Mega. Dalším krokem je zvolit čip, do kterého budeme nahrávat v Nástroje>Vývojová deska. V našem příkladě to bude \lq Arduino Uno\rq , pod čímž se skrývá čip Atmega328 nastavený na použití externího oscilátoru s frekvencí 16Mhz, který je na desce Arduino Uno. Toto nastavení, se zvýrazněnými důležitými parametry, je na obrázku \ref{fig:uno_settings}.

\begin{figure}[ht!]
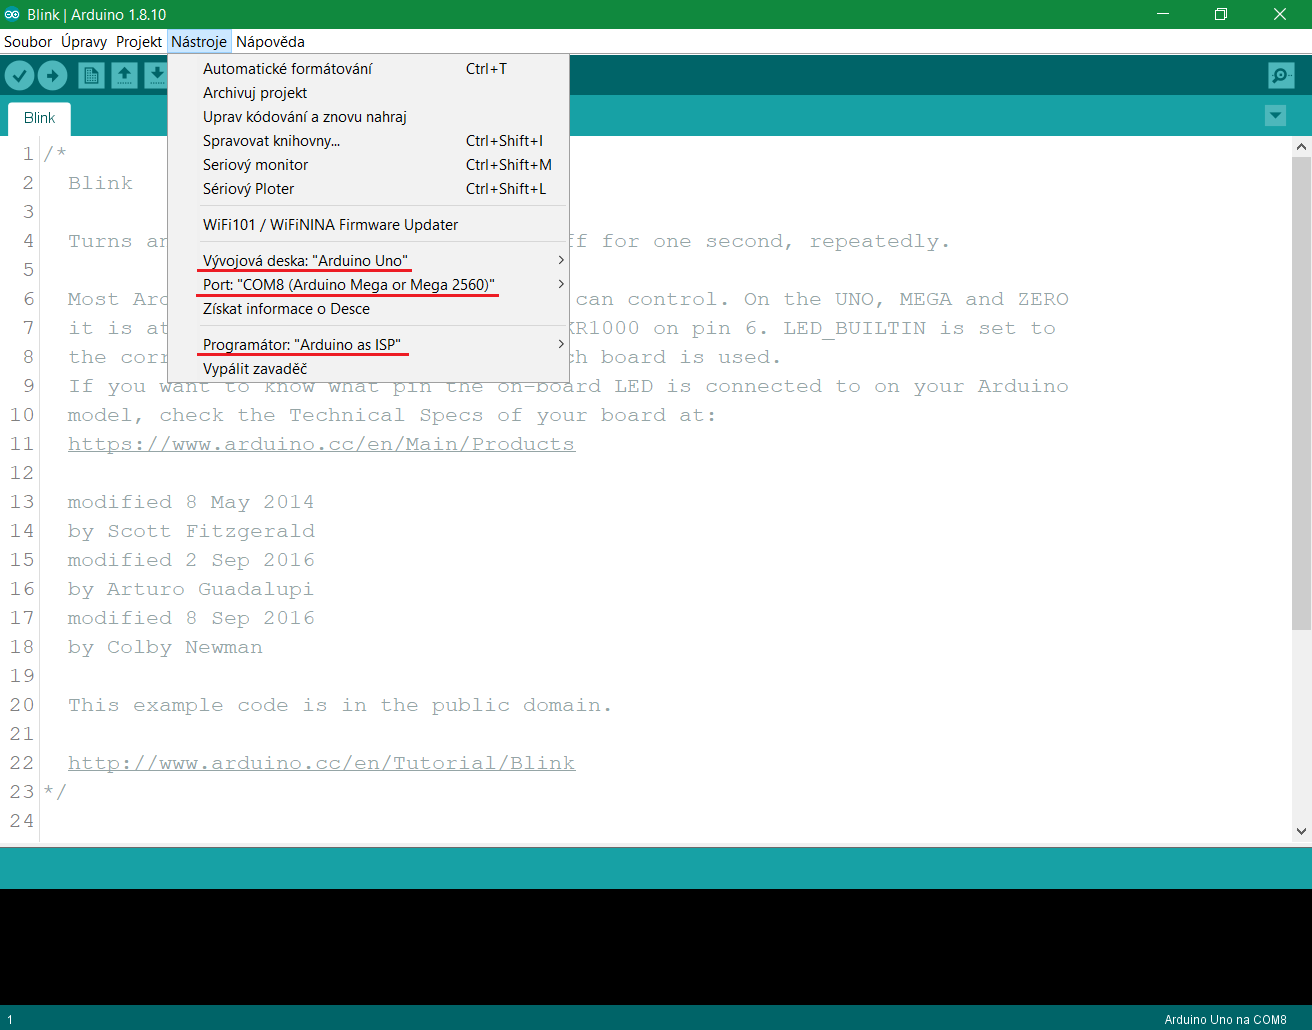
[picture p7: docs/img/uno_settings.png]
  
  \centering
  \caption{Nastavení Arduino IDE pro nahrávání do čipu ATmega328 s externím oscilátorem 16Mhz; zvýrazněny jsou nejdůležitější parametry.}
  \label{fig:uno_settings}
\end{figure}

Nahrávání do jiných mikrokontrolérů, kterými nejsou obsazeny desky Arduino, vyžaduje stažení příslušných knihoven. Pro čipy ATtiny může být použita například knihovna ATTinyCore \cite{attinycore}. Po jejím nainstalování se nám příslušné mikrokontroléry ukáží pod Nástroje>Vývojová deska a bude pro ně dostupné více nastavení. Možná nastavení, která nemusí být dostupná pro každý mikrokontrolér, jsou BOD (Brown-out detection; napětí, při kterém se čip vypně), číslování pinů, hodiny (vnitřní/vnější oscilátor a jeho frekvence) a mnoho dalšího. Příklad nastavení pro programování čipu ATtiny84 s interním oscilátorem 8Mhz je na obrázku \ref{fig:attiny84_settings}.

\begin{figure}[ht!]
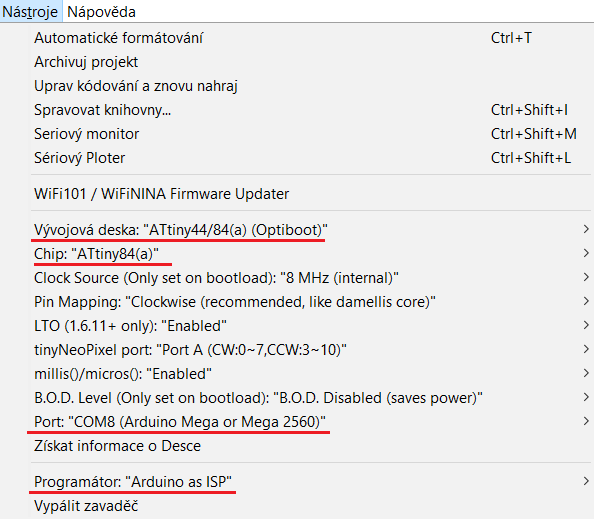
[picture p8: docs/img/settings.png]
  
  \centering
  \caption{Nastavení Arduino IDE pro nahrávání do čipu ATtiny84; zvýrazněny jsou nejdůležitější parametry.}
  \label{fig:attiny84_settings}
\end{figure}

V případě, že je toto první nahrávání do konkrétního čipu bude potřeba vypálit bootloader. To lze v Arduino IDE udělat pod Nástroje>Vypálit zavaděč. Tím se příslušné parametry, jako frekvence oscilátoru či BOD, vypálí do mikrokontroléru. Poté je již možné nahrávat program do čipu pod Projekt>Nahrát pomocí programátoru nebo pomocí zkratky Ctrl+Shift+U. 

Mikrokontrolér, do kterého jsme nahrávali kód pomocí programátoru, nebude následně možné programovat pomocí sériového portu. Tento způsob programování je využíván například při bězném nahrávání do desek Arduino Uno. Pokud tedy chceme čip vložit do desky Arduino Uno nebo podobné, bude nutné znovu vypálit bootloader pod Nástroje>Vypálit zavaděč. Poté již do čipu nenahrávejte s pomocí USP a vložte jej do desky Arduino Uno.

\subsection {Použití s AVRDUDE}

\begin{figure}[ht!]
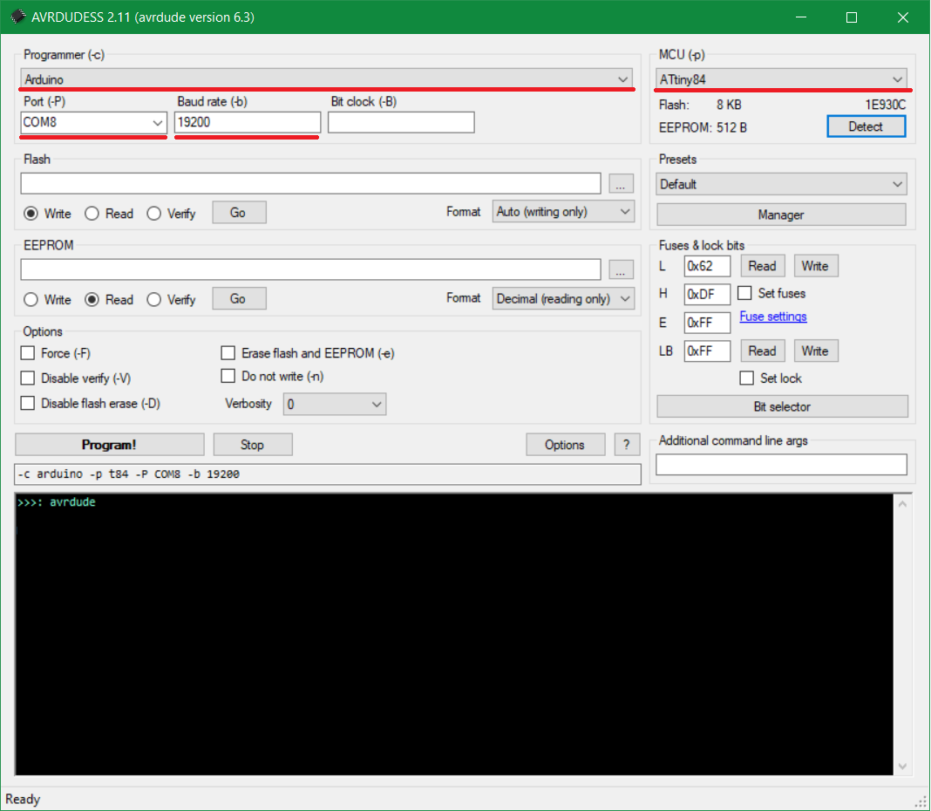
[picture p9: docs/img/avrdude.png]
  
  \centering
  \caption{Nastavení AVRDUDESS pro nahrávání do čipu Attiny84, zvýrazněny jsou nejdůležitější parametry.}
  \label{fig:avrdude}
\end{figure}

Podobně jako s Arduino IDE, lze nahrávat i programem AVRDUDE, případně s použitím UI verze zvané AVRDUDESS. Opět je nutné pouze zvolit port, programátor Arduino, cílový čip a tentokrát i rychlost komunikace 19200 baudů. Nastavení pro ATtiny84 je dostupné na obrázku \ref{fig:avrdude}. Hlavní výhodou AVRDUDE je, že pomocí něj jsme schopni nastavovat a číst fuse bits, číst a zapisovat do EEPROM či flash paměti či nastavovat lock bits. Lze pomocí něj do určité míry oživovat i zdánlivě mrtvé čipy.

\section {Nahrávání od USP \label{selfupload}}

Deska USP chrání řídící mikroprocesor na Arduino Mega proti nechtěnému flashování. V případě, že bude potřeba do něj nahrávat, je nutné nejdříve odstranit žlutý jumper s označením \lq self prog\rq , který se nachází na druhé straně desky než displej a tlačítka. Poté bude již možné nahrávat do Arduino Mega standardním způsobem.

\chapter*{Závěr}
\pagestyle{empty}
\addcontentsline{toc}{chapter}{Závěr}

Hlavním cílem projektu bylo vytvořit hardwarový výrobek, který bude reálně užitečný a výrazně zjednodušší nahrávání do (převážně) AVR čipů v pouzdře DIP. Tento cíl projekt splnil. Na hardwarové úrovni bylo implementováno i několik bonusových funkcí, jako například podpora vysokonapěťového programování, které pouze čekají na implementaci v softwaru.

Zařízení je funkční a bylo otestováno na několika mikrokontrolérech, které jsem měl k dispozici. Jeho spolehlivost by bylo možné dále zvýšit důkladnějším testování na dalších čipech a doladěním parametrů detekce. Také by bylo možné vytvořit uživatelsky přívětivé rozhraní, které by umožňovalo například volbu nahrávacího protokolu, případně poskytovalo některé funkce i bez připojení k počítači, k čemuž je také připraven potřebný hardware.

Během práce na projektu jsem se toho mnoho naučil nejen o AVR čipech a CMOS obvodech, které jsem využíval, ale také o elektrotechnice obecně. Získal jsem cenné zkušeností při návrhu plošného spoje, výběru potřebných komponent a zkoumání jejich vzájemných interakcí.  

%%% Seznam použité literatury
\printbibliography[title={Seznam použité literatury},heading={bibintoc}]

%%% Seznam obrázků
\openright
\listoffigures
\addcontentsline{toc}{chapter}{Seznam obrázků}

%%% Přílohy k práci, existují-li. Každá příloha musí být alespoň jednou
%%% odkazována z vlastního textu práce. Přílohy se číslují.

\part*{Přílohy}
\appendix

\renewcommand{\thefigure}{A.\arabic{figure}}

\setcounter{figure}{0}

\begin{figure}[ht!]
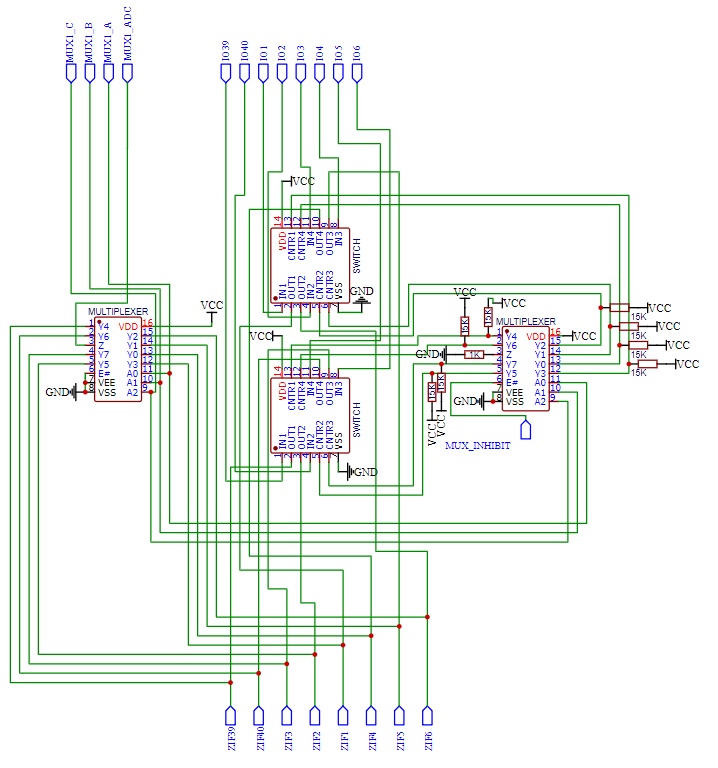
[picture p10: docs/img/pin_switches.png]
  
  \centering
  \caption{Úplné schéma obvodu připojeného k 8 pinům ZIF patice.}
  \label{appendix:pin_switches}
\end{figure}

\begin{figure}[ht!]
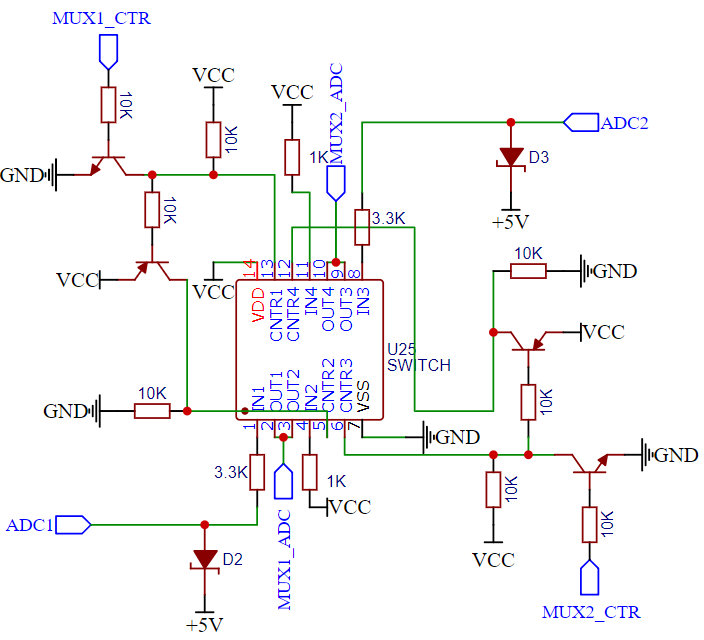
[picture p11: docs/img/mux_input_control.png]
  
  \centering
  \caption{Úplné schéma zapojení switche, který přepíná vstup do multiplexerů 1 a 2 mezi ADC pinem a 12V.}
  \label{appendix:mux_input_control}
\end{figure}

\begin{figure}[ht!]
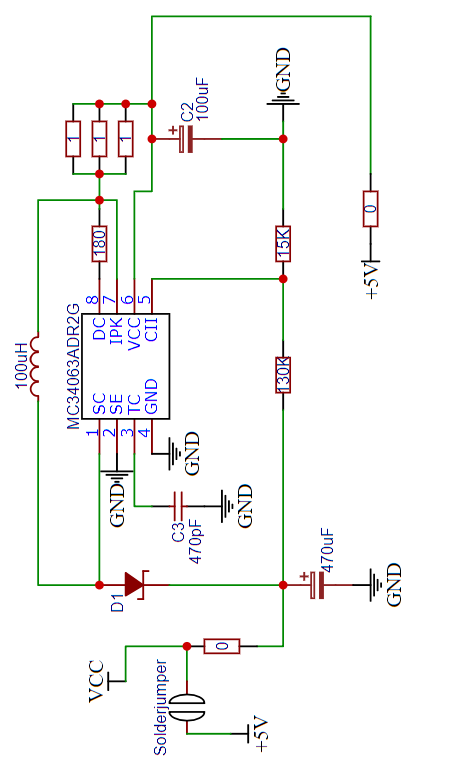
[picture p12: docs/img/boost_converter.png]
  
  \centering
  \caption{Úplné schéma obvodu step-up převodníku z 5 na 12 voltů. Obvod zahrnuje nula ohmové odpory a solder jumper, které umožňují jednoduché odpojení převodníku.}
  \label{appendix:boost_converter}
\end{figure}

\begin{figure}[ht!]
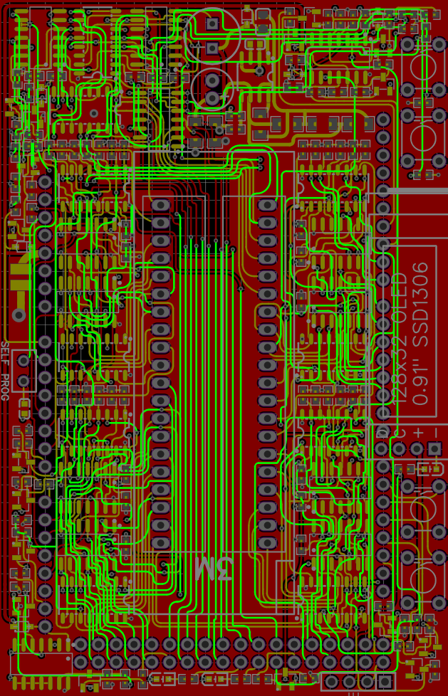
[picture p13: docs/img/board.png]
  
  \centering
  \caption{Zapojení plošného spoje. Žlutou barvou jsou vyznačeny spoje ve vrchní vrstvě, zelenou spoje spodní vrstvy a červenou spoje jedné z vnitřních vrstev. Druhá vnitřní vrstva není na obrázku zachycena.}
  \label{appendix:board}
\end{figure}

\end{document}

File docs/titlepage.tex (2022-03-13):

%%% Titulní strana práce a další povinné informační strany

%%% Titulní strana práce

\pagestyle{empty}
\pagenumbering{gobble}
\hypersetup{pageanchor=false}

\begin{center}
\LARGE
\textbf{GYMNASIUM JANA KEPLERA}\\
{\large Parléřova 2/118, 169 00 Praha 6}

\vspace{\stretch{3}}

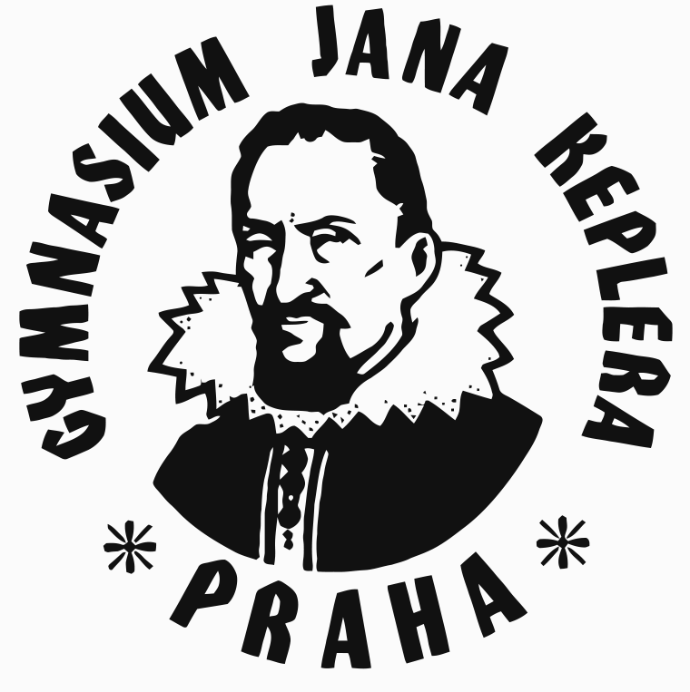
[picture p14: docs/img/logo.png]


\vspace{\stretch{3}}

{\Huge\bfseries\NazevPrace}

\vspace{8mm}
\mdseries{Maturitní práce}

\vspace{\stretch{8}}
\large
\begin{tabular}{rl}
Autor: & \AutorPrace \\
\noalign{\vspace{2mm}}
Třída: & \Trida\\
\noalign{\vspace{2mm}}
Školní rok: & 2021/2022\\
\noalign{\vspace{2mm}}
Předmět: & Informatika \\
\noalign{\vspace{2mm}}
Vedoucí práce: & \Vedouci \\
\end{tabular}

\vspace{20mm}
Praha, \DatumOdevzdani
\end{center}

\openright

\includepdf[]{zadani.pdf}

%%% Strana s čestným prohlášením k bakalářské práci

\hypersetup{pageanchor=true}
\cleardoublepage
\vspace*{\fill}
\section*{Prohlášení}
\noindent
\Prohlaseni

\vspace{2cm}
\noindent
V Praze dne \today
\hspace*{\fill}\small{\AutorPrace}
\vspace{1cm}

%%% Poděkování
\openright
\vspace*{\fill}
\section*{Poděkování}
\noindent
\Podekovani
\vspace{1cm}

%%% Povinná informační strana bakalářské práce
\openright
\section*{Abstrakt}
\noindent
\Abstrakt
\subsection*{Klíčová slova}
\noindent
\KlicovaSlova

\vfill

\section*{Abstract}
\noindent
\AbstraktEN
\subsection*{Keywords}
\noindent
\KlicovaSlovaEN

\openright
\pagenumbering{arabic}

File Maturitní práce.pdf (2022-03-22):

# GYMNASIUM JANA KEPLERA

### Parléˇrova 2/118, 169 00 Praha 6

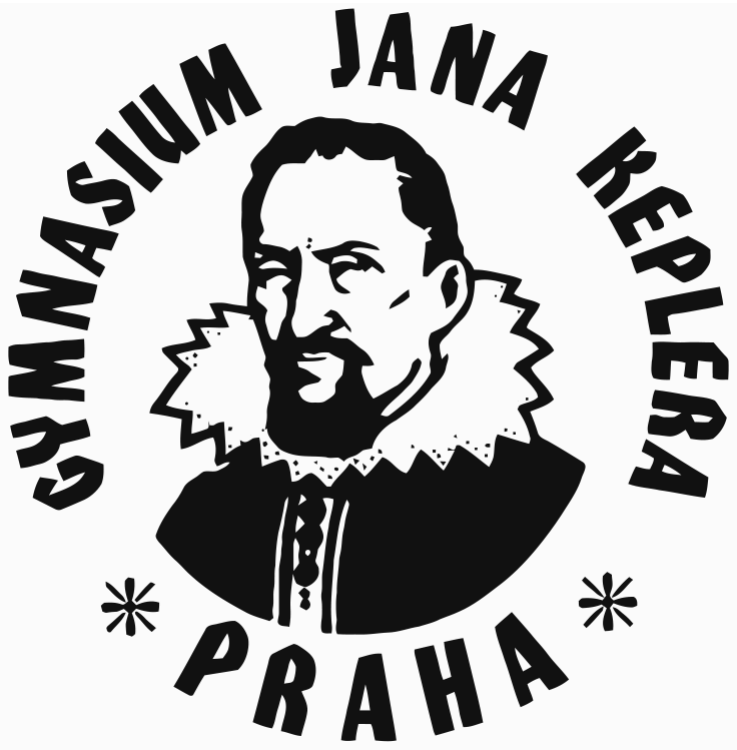
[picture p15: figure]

# Univerzální sériový programátor

# Maturitní práce

### Autor: Petr Šícho

### Tˇrída: R8.A

### Školní rok: 2021/2022

### Pˇredmˇet: Informatika

### Vedoucí práce: Bc. Emil Miler

### Praha, 25.3.2022

# GYMNASIUM JANA KEPLERA Kabinet informatiky

# ZADÁNÍ MATURITNÍ PRÁCE

Student: | Petr Šícho
Tˇrída: | R8.A
Školní rok: | 2021/2022
Platnost zadání: | 30. 9. 2022
Vedoucí práce: | Bc. Emil Miller
Název práce: | Univerzální sériový programátor

Pokyny pro vypracování: Cílem práce je vymyslet a vytvoˇrit univerzální programátor minimálnˇe pro nejznámnˇejší ˇcipy AVR, tedy ˇrady Attiny a Atmega. Univerzální programátor má ulehˇcit nahrávání do zmínˇených ˇcip ˚u, bez nutnosti zapojovat cokoliv na nepájivém poli. Programátor by mˇel detekovat jaký je do nˇej vložený ˇcip a umožnit do nˇej nahrávat z poˇcítaˇce. Za dodateˇcné, vedlejší, funkce by se dalo napˇríklad považovat možnost nahrávat do ˇcip ˚u pˇres pin header, tedy bez vyndavání ˇcipu z postaveného obvodu. Výsledkem projektu by minimálnˇe mˇel být funkˇcní

prototyp programátoru, který je použitelný pro specifikovaný úˇcel.

## Doporuˇcená literatura:

## URL repozitáˇre:

## https://github.com/Xmen097/USP

student | vedoucí práce

## V Praze dne 22. 10. 2021

# Prohlášení

Prohlašuji, že jsem svou práci vypracoval samostatnˇe a použil jsem pouze prameny a literaturu uvedené v seznamu bibliografických záznam ˚u. Nemám žádné námitky proti zpˇrístupˇnování této práce v souladu se zákonem ˇc. 121/2000 Sb. o právu autorském, o právech souvisejících s právem autorským a o zmˇenˇe nˇekterých zákon ˚u (autorský zákon) ve znˇení pozdˇejších pˇredpis ˚u.

V Praze dne 22. bˇrezna 2022 | Petr Šícho

# Podˇekování

Chtˇel bych podˇekovat pˇredevším open hardware komunitˇe, specificky pak Arduino komunitˇe, na jejíchž fórech jsem našel znaˇcné množství informací. Dále dˇekuji Bc. Emilovi Milerovi za pomoc pˇri vedení této maturitní práce.

# Abstrakt

Tato maturitní práce si klade za cíl zjednodušit proces programování a nahrávání kódu do mikrokontrolér ˚u v pouzdˇre DIP. Univerzální sériový programátor (USP), který v rámci této práce vznikl, je zaˇrízení, které je schopné automaticky detekovat rozložení vývod ˚u ˇcipu vloženého do ZIF patice. Na základˇe toho rozpozná o který mikrokontrolér se jedná a uzp ˚usobí pro nˇej nahrávací obvod. Teoreticky by mˇel USP umˇet programovat všechny mikrokontroléry pracující na napˇetí 5 volt ˚u a podporovat dostateˇcnˇe pomalé bit-banging programovací protokoly, vˇcetnˇe tˇech, které vyžadují vysoké napˇetí (12V) pro resetování. Aktuálnˇe je implementována podpora rodin ATtiny a ATmega od výrobce Atmel. Na softwarové úrovni USP pracuje na protokolu Arduino ISP.

## Klíˇcová slova

programátor, mikrokontrolér, AVR, nahrávaˇc, USP

# Abstract

This thesis aims to simplify the process of programming and uploading code to microcontrollers in a DIP package. The Universal Serial Programmer (USP), which was created in this work, is a device that is able to automatically detect the distribution of terminals on a chip inserted into the ZIF socket. Based on this, it recognizes which microcontroller is present and adapts the programming circuit for it. Theoretically, the USP should be able to program all microcontrollers operating at 5 volts and supporting sufficiently slow bit-banging programming protocols, including those that require high voltage (12V) for reset. A support is current implemented for the ATtiny and ATmega families from the manufacturer Atmel. At a software level, the USP is working on the Arduino ISP protocol.

## Keywords

programmer, microcontroller, AVR, uploader, USP

# Obsah

1 Teoretická ˇcást | 3
2 Implementace | 7
2.1.2 | Rídící mikroprocesor | ˇ | 7
3 Technická dokumentace | 17
Závˇer | 21
Seznam použité literatury | 23
Seznam obrázk ˚u | 25

# 1. Teoretická ˇcást

Existuje nepˇreberné množství r ˚uzných ˇcip ˚u a s nimi podobné množství r ˚uzných rozložení vývod ˚u, které nejsou jednotné ani u jedné velikosti a jednoho výrobce. Pro každé rozložení pin ˚u mikrokontroléru je nutné mít externí programovací obvod. Cílem práce je sjednotit tyto programovací obvody do jednoho univerzálního, který se pˇrizp ˚usobí vloženému ˇcipu. Fungování USP lze rozdˇelit na dvˇe ˇcásti - detekovat ˇcip a následnˇe umožnit jeho programování.

Pro univerzální programátor není možné použít žádný dedikovaný hardware, který by zajišt’oval nahrávání. Naopak je vhodné použítí univerzálních vstupních / výstupních pin ˚u neboli GPIO¹ pin ˚u. I pˇres snahu o maximální univerzálnost není reálné docílit podpory úplnˇe všech existujících ˇcip ˚u. Jako minimální požadovanou funkcionalitu jsem tedy bral podporu ˇcip ˚u AVR od výrobce Atmel, konkrétnˇe pak ˇrady ATmegy a ATtiny, které zahrnují mikrokontroléry, jež pohání známé desky Arduino. Pˇresto se domnívám, že vlastnosti tˇechto ˇcip ˚u, na kterých je detekce a nahrávání postaveno, budou do velké míry pˇrenositelné i na jiné rodiny ˇci výrobce ˇcip ˚u.

# 1.1 Detekce

Základem detekce je poznat jak velký ˇcip je - tedy kolik má vývod ˚u. Tím bychom mohli v prvním pˇriblížení detekce radikálnˇe omezit poˇcet potenciálních kandidát ˚u. Pˇri zahrnutí jen nˇekolika model ˚u, jednoho pro každou velikost, bychom tak mˇeli detekci témˇeˇr hotovou. Bylo by však nutné arbitrárnˇe stanovit tyto podporované ˇcipy, pˇriˇcemž pˇri vložení jiného, at’ tˇreba ze stejné rodiny, který má prohozené piny GND a VCC, by došlo pravdˇepodobnˇe k jeho zniˇcení. Naší ambicí tedy bude zjistit o ˇcipu co nejvíce informací, díky nimž budeme schopni rozeznávat mezi co nejvˇetším poˇctem r ˚uzných ˇcip ˚u.

Pˇri detekci si musíme dávat pozor, abychom náhodou mikrokontrolér nepoškodili. Ideálnˇe bychom se chtˇeli držet v hodnotách, které povoluje jeho datasheet. Problém je, že to, o co se pokoušíme, není standardní zacházení s ˇcipy a v datasheetu tak nenalezneme konkrétní povolené hodnoty a situace, kterým m ˚užeme ˇcip bezpeˇcnˇe vystavit. Z datasheetu vybraných AVR ˇcip ˚u [5, 4, 2, 3] m ˚užeme alespoˇn urˇcit nˇekteré spoleˇcné zásady, kterých když se budeme držet, tak minimalizujeme poškození ˇcipu. Konkrétnˇe se jedná o:

- Nevystavovat žádný pin napˇetí nižšímu než −0.5V
- Nevystavovat žádný pin, kromˇe RESETu, napˇetí vyššímu než Vcc + 0.5V
- Nevystavovat RESET napˇetí vyššímu než 13V
- Nenechat mezi žádný dvˇema piny nezapojeného ˇcipu téct nezanedbatelnˇe velký proud po nezanedbatelnˇe dlouhou dobu²

Pˇri splnˇení tˇechto podmínek by mˇel být ˇcip dostateˇcnˇe chránˇen obvody, které bˇežnˇe slouží k ochranˇe pˇred elektrostatickým výbojem (ESD).

1z anglického General-purpose input/output, tedy pin, který se umí chovat bud’ jako digitální vstup, nebo výstup, pˇriˇcemž mezi tˇemito módy je možné pˇrepínat.
2Pro naše úˇcely budeme považovat za zanedbatelný proud ˇrádu mikroampér a ˇcas mikrosekund.

Teoretická ˇcást

## 1.1.1 Detekce velikosti a polohy

Pro detekci velikosti ˇcipu m ˚užeme využít toho, že každá reálná souˇcástka, kromˇe svých primárních vlastností, vykazuje také elektrickou kapacitu. To bude jistˇe platit i pro spoje a souˇcástky uvnitˇr integrovaných obvod ˚u. Elektrická kapacita pin ˚u jednoduchých CMOS³
ˇcip ˚u [7, 8, 13] se pohybuje v jednotách pikofarad ˚u. Není mi znám žádný zp ˚usob pˇrímého mˇeˇrení elektrické kapacity, budeme tedy muset provést mˇeˇrení nepˇrímé a dostateˇcnˇe pˇresné. Jednou z možností je kapacitor pomalu nabíjet nebo vybíjet a mˇeˇrit ˇcas, který k tomu budeme potˇrebovat. Zkusíme odhadnout jak pˇresné takové mˇeˇrení bude s pomocí rovnice definující energii elektrického kondenzátoru

E =

1

2

CU²
(1.1)

Budeme-li kapacitor nabíjet napˇetím U a proudem I po dobu t, m ˚užeme psát

Wmax = U ·I· t | (1.2)

Jedná se o horní odhad vykonané práce, která poˇcítá s nulovým odporem a nulovým elektrickým potenciálem kapacitoru. Reálná energie pˇredaná kapacitoru bude nižší, což nám však nevadí. Úpravou tˇechto dvou vztah ˚u m ˚užeme vyvodit úmˇernost

C ≃ t/R | (1.3)

Zjistili jsme, že kapacita je pˇrímo úmˇerná ˇcasu, po který jsme kapacitor nabíjeli, a nepˇrímo úmˇerná
odporu, pˇres který jsme nabíjeli.⁴ Cas budeme schopni mˇeˇrit velice pˇresnˇe ˇ | 5
, ˇrádovˇe v mikrosekundnách (10−6
s). Reknˇeme, že pin ˇcipu má kapacitu ˇ | 10pF = 10−11F. Dosazením do vztahu (1.3) zjistíme,
že k jejímu zmˇeˇrení budeme potˇrebovat nabíjecí odpor o velikosti 100kΩ. To nebude problém, mˇe-ˇrení vypadá proveditelnˇe.

Díky schopnosti zmˇeˇrit kapacitu na každém z pin ˚u socketu zjistíme nejenom jak velký ˇcip je, ale zároveˇn i kde v socketu je vložen. Není tedy nutné nijak specifikovat na jakou pozici v socketu má být ˇcip pro nahrávání vložen.

## 1.1.2 Detekce speciálních pin ˚u

Každý mikrokontrolér má kromˇe vstupních / výstupních pin ˚u i speciální piny, které plní nˇejakou zvláštní funkci. Napˇríklad je to RESET pin, napájecí piny (GND a VCC) nebo piny hodin (XTAL). Tyto piny by mohly vykazovat rozdílné elektrické vlastnosti a možná i rozdílnou kapacitu. Vzhledem k tomu, že napájecí piny jsou vnitˇrnˇe pˇripojené k všemožným souˇcástem mikrokontroléru, lze hlavnˇe u tˇechto pin ˚u oˇcekávat vyšší kapacitu. Tu bychom pˇri dostateˇcnˇe pˇresném mˇeˇrení kapacity detekovat a rozpoznat tak polohu napájecích pin ˚u.

## 1.1.3 Rozpoznání VCC od GND

Pˇri špatném rozpoznání vloženého mikrokontroléru m ˚uže nejvˇetší poškození zp ˚usobit pˇrevrácení pin ˚u GND a VCC. Abychom se tohoto rizika vyvarovali, je nutné rozpoznávat s jistotou VCC od

3Complementary metal-oxide semiconductor; technologie výroby integrovaných obvod ˚u.
4Ke stejnému výsledku bychom došli i použitím rozmˇerové analýzy.
5Pˇresnost mˇeˇrení ˇcasu je omezena frekvencí oscilátoru ˇrídícího mikrokontroléru, bˇežnˇe se pohybuje v desítkách megahertz ˚u.

Teoretická ˇcást

GND. Tím zároveˇn obecnˇe snížíme šanci na špatné rozpoznání ˇcipu.

Využijeme ochranných diod, které jsou pˇripojeny ke každému IO pinu mikrokontroléru, jak ukazuje obrázek 1.1. Povšimnˇeme si, že dioda spojující pin s GND smˇeˇruje opaˇcnˇe, než dioda spojující pin s VCC. Díky tomu bychom mˇeli být schopni rozpoznat, zda je urˇcitý pin GND ˇci VCC.

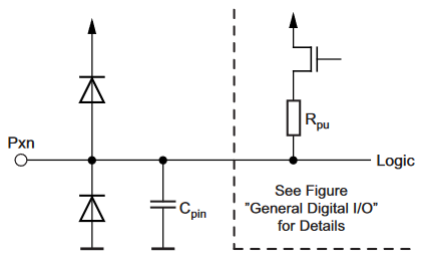
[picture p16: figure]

Obrázek 1.1: Schéma vnitˇrního zapojení IO pinu mikrokontroléru [4, str. 58].

Pin GND m ˚užeme detekovat následovnˇe. Budeme znát úbytek napˇetí na diodˇe mezi pinem a GND Ud. Pˇrivedeme-li na pin GND napˇetí U pˇrevyšující Ud, mˇeli bychom na všech IO pinech detekovat napˇetí U − Ud. Z bezpeˇcnostních d ˚uvod ˚u by napˇetí U by mˇelo být co nejmenší možné, ideálnˇe U < 0.5V. Napˇetí pˇrivedeme pˇres dostateˇcnˇe velký odpor tak, aby mikrokontrolérem a diodou tekl co nejmenší proud. S malým procházejícím proudem budeme mít také menší úbytek napˇetí na diodˇe (menší, než bˇežnˇe udávaných ∼ 0.7V)

Obdobným zp ˚usobem je možné detekovat pin VCC. Staˇcí na libovolný (nebo lépe postupnˇe na všechny) IO pin pˇrivést napˇetí U a na pinu VCC by se nám vždy mˇelo ukázat napˇetí U − Ud.

## 1.1.4 Závˇer

S touto výbavou bychom mˇeli být schopni dostateˇcnˇe detailnˇe rozpoznat mikrokontroléry ATmega a ATtiny. Díky rozpoznáním GND a VCC budeme schopni ˇcip bezpeˇcnˇe napájet. Nebude pak problém, kdybychom chtˇeli rozšíˇrit podporované ˇcipy a vyskytly by se nám dva ˇcipy, které mají na stejných místech GND a VCC, ale na r ˚uzných místech piny potˇrebné pro nahrávání. V této situaci bychom postupnˇe vyzkoušeli r ˚uzná rozložení nahrávacích pin ˚u, až bychom našli to správné.

# 1.2 Nahrávání

Po detekování ˇcipu nám už zbývá pouze do nˇej nahrát. Vzhledem k tomu, že pˇresnˇe nevíme jaké rozložení pin ˚u bude ˇcip mít, musíme použít tzv. bit-banging⁶
. Díky tomu se nemusíme pˇri stavbˇe hardwaru nahrávaˇce omezovat na urˇcité ˇcipy, ale budeme schopni teoreticky obsluhovat všechny ˇcipy, které nevyžadují pˇríliš velké komunikaˇcní rychlosti⁷ a existuje pro nˇe bit-banging implementace nahrávání. Nebude tak ani obtížné obmˇeˇnovat nahrávací protokoly pro r ˚uzné ˇcipy nebo situace.

6Softwarová implementace urˇcitého protokolu, která pˇrímo generuje protokolem specifikovaný signál, bez použití specializovaného hardwaru.
7Maximální rychlost komunikace je tím, jak rychle jsme schopni zpracovávat odchozí a pˇríchozí data.

Teoretická ˇcást

Komplikací m ˚uže být, že nˇekteré nahrávací protokoly vyžadují použití vyššího napˇetí. U AVR ˇcip ˚u jde konkrétnˇe o protokoly HVSP (high voltage serial programming) a HVPP (high voltage parallel programming), které se hodí pˇri urˇcitém nastavení mikrokontroléru, kdy není možné standardní programování.⁸ Vysokým napˇetím je v obou pˇrípadech myšleno 12 volt ˚u [11]. Vzhledem k tomu, že ve valné vˇetšinˇe pˇrípad ˚u lze programovat mikrokontrolér bez použití vysokého napˇetí, bral jsem jeho dostupnost spíše jako bonus než nutný požadavek. High-voltage programováním se tedy budeme zabývat pouze z hardwarového hlediska.

# 1.3 Shrnutí požadovaných funkcí

V této sekci si shrneme funkce, které budeme potˇrebovat pro úspˇešnou detekci a nahrávání do ˇcip ˚u. Tˇemito funkcemi by mˇel disponovat každý z pin ˚u socketu, nebot’ nevíme, kde se zrovna ˇcip ocitne. Nˇekteré funkce budou komplexní (pˇreˇcti kapacitu pˇripojenou k pinu), u jiných se bude jednat o nˇejaký elementární stav (pˇripojení k zemi/5V).

1. 5V s proudem >20 mA je potˇreba pro napájení ˇcipu. Proud 20 mA by mˇel staˇcit pro napájení AVR ˇcip ˚u [5, 4]. Nˇekteré vˇetší ˇcipy za urˇcitých okolností mohou mít spotˇrebu vˇetší než 20 mA, ale mají také více separátních napájecích pin ˚u, mezi které se proud rozloží [6, str. 286-323].
2. 0V (GND) s proudem >20 mA je potˇreba též pro napájení ˇcipu.
3. 5V s libovolnˇe malým proudem reprezentuje logický stav 1 pˇri komunikaci, odebíraný proud bˇehem komunikace bude zanedbatelný.
4. 0V (GND) s libovolnˇe malým proudem reprezentuje logický stav 0 pˇri komunikaci.
5. Ctení digitální hodnoty ˇ | pro ˇctení odpovˇedi ˇcipu pˇri nahrávání; standardní funkce GPIO pin ˚u.
6. Pˇreˇctení kapacity pro detekci ˇcipu.
7. Napˇetí pˇribližnˇe 0.4-0.5V je potˇreba pro rozpoznání GND a VCC, viz sekce 1.1.3.
8. Pˇreˇctení napˇetí na pinu je také potˇreba pro rozpoznání GND a VCC.
9. 12V bude potˇreba pokud budeme chtít high-voltage programování.
10. Nepˇripojeno k niˇcemu. Piny, které nevyužíváme k jiné funkci, by se mˇely chovat tak, jako kdyby nebyly k niˇcemu pˇripojené.

8
Jde napˇr. o situace kdy je vypnuté resetování pomocí RESET pinu, protože ho chceme použít na jinou funkci.

# 2. Implementace

Implementace projektu mˇela dvˇe fáze. Nejprve bylo potˇreba navrhnout hardwarovou ˇcást - vymyslet a vyzkoušet jednotlivé ˇcásti obvodu tak, aby plnily požadované funkce. Poté bylo potˇreba všechny spojit do jednoho celku, který se vyrobí jako plošný spoj. Po osazení plošného spoje souˇcástkami a otestování základní funkˇcnosti následoval vývoj softwaru. Jako první probíhala implementace low-level komunikace s jednotlivými souˇcástkami, pak pˇrišly na ˇradu high-level funkce detekce.

Pojd’me si nyní jednotlivé fáze rozebrat detailnˇeji.

# 2.1 Hardware

Pˇrevážná ˇcást práce na hardwaru probíhala s pomocí nepájivého pole, na kterém jsem postupnˇe testoval jednotlivé ideje uvedené v teoretické ˇcásti práce. V následujících sekcích si rozebereme jaké souˇcástky byly použity a jak se pomocí nich implementují požadované funkce ze sekce 1.3.

## 2.1.1 Vkládání ˇcipu

Jako patici, do které se bude vkládat ˇcip k programování, jsem zvolil ZIF (zero insertion force) socket. Jak již jméno napovídá, pro vložení ˇcipu do patice není nutné užití síly. Staˇcí ˇcip položit na patici a pomocí páˇcky na stranˇe patice ˇcip zajistit, ˇcímž vznikne spolehlivý kontakt s piny ˇcipu. Nehrozí tak ohnutí nožiˇcek ˇcipu a jeho vložení i vyndání je velmi rychlé. Nevýhodou ZIF socketu je o trochu vyšší poˇrizovací cena a vˇetší velikost, ale i pˇresto se v našem pˇrípadˇe urˇcitˇe vyplatí. Konkrétnˇe jsem zvolil patici se 40 piny (dvaceti na každé stranˇe), která by mˇela postaˇcovat pro naprostou vˇetšinu DIP¹ pouzder. Patice podporuje vložení jak úzké (0.3”), tak široké (0.6”) varianty DIP.

## 2.1.2 Rídící mikroprocesor ˇ

Je potˇreba zvolit mikroprocesor, který bude ovládat celý nahrávaˇc. Volil jsem mezi mikrokontroléry AVR, s kterými jsem nejvíce obeznámen a které také umí jednoduše komunikovat s Arduino IDE. Zásadní otázkou je kolik budeme potˇrebovat GPIO pin ˚u k ovládání USP. Urˇcitˇe bude potˇreba jeden pin pro každý pin ZIF patice, tedy minimálnˇe 40 pin ˚u. Další desítky pin ˚u budou potˇreba pro ovládaní komponent a souˇcástek, o kterých se budu detailnˇeji zmiˇnovat v dalších sekcích. Teoreticky by bylo možné pˇridat další piny pomocí shift registrer ˚u ˇci IO expander ˚u. Tím by však utrpˇela rychlost komunikace a vzrostla by komplexita desky a tím i prostor pro chyby. Rozhodl jsem se tedy pro jeden co nejvˇetší ˇcip, mikrokontrolér ATmega2560 v pozdˇre TQFP100, který má 84 GPIO pin ˚u [2].

Nejprve jsem plánoval, že bych využil dostupných schémat Arduino desek a v upravené podobˇe je pˇrímo zakomponoval do desky nahrávaˇce. To by umožnilo využít ˇrídící ˇcip bez omezení. Na druhou stranu by tím extrémnˇe vzrostla komplexita desky a také celková cena. Nakonec jsem se tedy

1Dual in-line package; pouzdro s THT piny s rozteˇcí 2.54mm.

Implementace

rozhodl programátor vyvinout jako shield (nasazovací desku) na Arduino Mega s mikroprocesorem ATmega2560. Nevýhodou tohoto postupu m ˚uže být snad jen to, že Arduino mega nám dává k dispozici pouze 70 z 84 GPIO pin ˚u, ale i to by mˇelo pro tento projekt staˇcit [1].

## 2.1.3 Základní funkcionalita pin ˚u

Nyní pˇrichází na ˇradu implementace požadovaných funkcí popsaných v sekci 1.3. Jenom tím, že ke každému pinu ZIF socketu bude pˇripojený GPIO pin, zajistíme funkce 3, 4, 5, které GPIO piny zvládají nativnˇe. Funkce 1 a 2, které vyžadují minimální proud 20 mA, také s trochou opatrnosti zvládneme. Digitální piny ATmegy2560 dokáží dodávat maximální proud 40 mA [2, str. 355-356]. Musíme tedy jen dát pozor na to, aby další souˇcástky, které budou zapojeny mezi GPIO pinem a pinem ZIF socketu nemˇely pˇríliš velký odpor nebo nevyžadovaly více omezený protékající proud.

Desátý požadavek vyžaduje trochu zamyšlení. Pin urˇcitˇe nebude možné fyzicky odpojit, to bychom museli provést manuálnˇe. Budeme tedy alespoˇn chtít minimalizovat proud, který m ˚uže skrz tento ‘odpojený’pin téct. Když nastavíme GPIO pin jako vstupní, bude ve stavu s tzv. vysokou impedancí, tedy poteˇce jím malý proud. Datasheet specifikuje maximální proud jako 1µA, typický proud lze oˇcekávat výraznˇe menší [2, str. 355]. Odpojení si navíc m ˚užeme pojistit použitím analogového pˇrepínaˇce, u kterého je udáván maximální proud 100nA a typický 0.05nA [13, str. 3].

## 2.1.4 Zapojení multiplexer ˚u

Implementaci funkcí 6, 7, 8 a 9 si zjednodušíme pozorováním, že v jednu chvíli bude daná funkce potˇrebná pouze na jednom pinu. Nemusíme ji tedy implementovat 40x, ale m ˚užeme použít multiplexery k spojení urˇcitého pinu s nˇeˇcím, co nám funkci zajistí. Napˇetí na pinu budeme ˇcíst pomocí ADC² pˇrevodníku. Atmega2560 disponuje jedním ADC pˇrevodníkem, který je ale vnitˇrnˇe multiplexován na 16 GPIO pin ˚u. Pomocí dalších multiplexer ˚u rozšíˇríme tuto funkcionalitu na všech 40 pin ˚u.

Multiplexery se standardnˇe vyrábí s 2

n kanály, které se ovládají pomocí n pin ˚u. Zvolil jsem 8 kanálové multiplexery [7], tedy s 3 ovládacími piny. Pro obsluhu 40 pin ˚u jich bude potˇreba celkem
5. Multiplexery jsou pˇripojeny k pin ˚um ZIF socketu zp ˚usobem znázornˇeným na obrázku 2.1.

Obrázek 2.1: Schéma zapojení mulitplexer ˚u k pin ˚um ZIF patice.

Díky tomuto zp ˚usobu zapojení budeme schopni odhalit závadu na multiplexeru pˇri rozpoznávání ˇcipu, nebot’ i nejmenší mikrokontrolér, který má pouzdro DIP8 se 4 piny na každé stranˇe, bude mít vždycky alespoˇn dva piny v r ˚uzných multiplexerech. Nestane se tedy, že by kv ˚uli závadˇe na jednom multiplexeru (ta m ˚uže být zp ˚usobená i tˇreba dotekem uživatele, kterým se zvýší kapacita) byl ˇcip chybnˇe rozpoznán.

2Analogovˇe digitální pˇrevodník; zaˇrízení, které pˇrevede analogový signál (napˇetí) v urˇcitém rozsahu na digitální tvar s urˇcitým poˇctem bit ˚u, v našem pˇrípadˇe se jedná o pˇrevodník 10-bitový.

Implementace

## 2.1.5 Napˇet’ový dˇeliˇc

Napˇetí 0.4-0.5V, jak si žádá sedmý požadavek, vytvoˇríme pomocí napˇet’ového dˇeliˇce. Zde se nám budou hodit již výše zmínˇené multiplexery. Dˇeliˇc napˇetí bude totiž právˇe mezi GPIO pinem a multiplexovaným pinem. Na každém GPIO pinu je možné zapnout tzv. pullup rezistor, který pin pˇripojí pˇres odpor s pˇribližnou velikostí 30 − 40kΩ³ k 5 volt ˚um. Kýžené napˇetí pˇribližnˇe p ˚ul voltu vytvoˇríme dalším rezistorem s velikostí 3.3kΩ⁴ k zemi. Zapojení dˇeliˇce napˇetí na pinu je vidˇet na obrázku 2.2

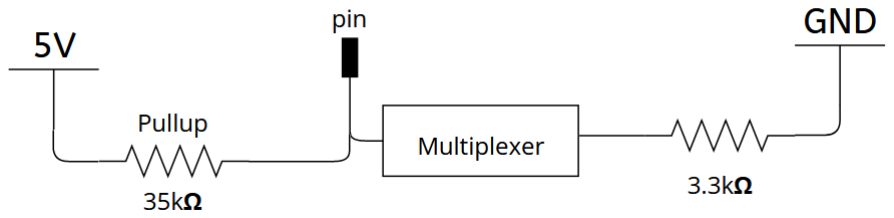
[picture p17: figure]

Obrázek 2.2: Schéma dˇeliˇce napˇetí.

## 2.1.6 Mˇeˇrení kapacity

Kapacitu lze mˇeˇrit, jak jsme vyvodili v sekci 1.1.1, pomocí pomalého nabíjení - tedy nabíjení pˇres dostateˇcnˇe velký rezistor. Vypoˇcítali jsme, že by se nám hodil rezistor s odporem 100kΩ. Pˇripojovat takový odpor k pin ˚um by si však vyžádalo dalších multiplexer ˚u nebo switch ˚u. M ˚užeme ale využít stejných pullup rezistor ˚u, které využíváme pro napˇet’ový dˇeliˇc. Ty jsou o nˇeco menší a mohlo by se stát, že kapacitor nabijeme pˇríliš rychle. M ˚užeme ale využít ADC pˇrevodníku, který máme multiplexovaný k pin ˚um. P ˚uvodnˇe jsme chtˇeli mˇeˇrit ˇcas, za který nabijeme plnˇe kapacitor, což bychom zjišt’ovali pomocí digitálního vstupu GPIO pin ˚u. M ˚užeme to ale provést i opaˇcnˇe. Kapacitor budeme nabíjet nˇejaký konstantní ˇcas, a poté pomocí ADC pˇrevodníku zjistíme napˇetí na kapacitoru. Cím vyšší napˇetí bude, tím více jsme kapacitor nabili a tím je tedy kapacitor menší. Opaˇcnˇe by šlo ˇ i kapacitor plnˇe nabít a poté ho nechat samovolnˇe vybíjet. Poˇckáme konstantní ˇcas a opˇet pomocí ADC pˇrevodníku zjistíme, jak moc se vybil.

Pˇri testování se ukázalo, že pro mˇeˇrení kapacity se nám velmi hodí i dˇeliˇc napˇetí, podrobnˇeji viz sekce 2.2.3

## 2.1.7 Napˇetí 12 volt ˚u

Poslední funkcionalitou, kterou nám zbývá implementovat je dostupnost napˇetí 12 volt ˚u. To m ˚užeme na pin pouštˇet pomocí stejných multiplexer ˚u, které využíváme k pˇripojení ADC pˇrevodníku. Staˇcí pomocí switche CD4066B [8] pˇrepínat zdroj multiplexeru mezi 12 volty a ADC pˇrevodníkem. Zapojení tohoto obvodu pro multiplexer 1 a 2 je vyobrazeno v pˇríloze A.2. Od použitého switche nepožadujeme žádné zvýšené nároky ohlednˇe proudu, pro HVSP i HVPP nám staˇcí malý proud.

3Datasheet udává, že odpor bude vždy vˇetší než 20kΩ a menší než 50kΩ. Vzhledem k tomu, že tyto hodnoty jsou pro teplotní rozmezí od -55°C do 125°C m ˚užeme konstatovat, že pˇri pokojové teplotˇe bude odpor pˇribližnˇe mezi 30 − 40kΩ.
4Chceme dˇeliˇc napˇetí pˇribližnˇe 1:10, hodnotu odporu jsem zvolil o nˇeco nižší, protože i samotný multiplexer bude mít urˇcitý odpor (asi 100 ohm ˚u).

Implementace

Problém je, že náš ˇrídící mikrokontrolér, ale ani vˇetšina dobˇre dostupných multiplexer ˚u, nepodporuje vyšší napˇetí než 5 volt ˚u. S trochou snahy se dají najít i multiplexery podporující 12 volt ˚u.
Rídíci ˇcip, jehož piny odolají napˇetí ˇ | 12 volt ˚u, ale prakticky není možné najít. Budeme proto muset
piny ˇrídíciho mikrokontroléru odpojit pˇredtím, než pˇripojíme 12 volt ˚u. K tomu využijeme analogové switche MC14066B [13]. Vzhledem k tomu, že pˇres tyto switche budeme mimo jiné napájet ˇcip, který budeme chtít programovat, musí podporovat pr ˚utok proudu alespoˇn 20mA.
| 5

Každý switch má 4 kanály, které dokáže pˇrepínat pomocí 4 ovládacích pin ˚u. Není však možné ani potˇrebné ovládat každý z tˇechto pin ˚u individuálnˇe, na to bychom totiž spotˇrebovali dalších 40 pin ˚u. Šlo by pomocí tranzistor ˚u a odpor ˚u detekovat zvýšené napˇetí a pˇrepnout ovládací pin switche. To by však vyžadovalo znaˇcné množstí externích komponent - na každý pin jeden tranzistor a nˇekolik odpor ˚u. Lepší ˇrešení je založené na faktu, že 12 volt ˚u bude vždy pˇripojené na pinu, který je multiplexován. Toho využijeme a pˇridáme další multiplexer, který bude mít stejnˇe zapojené ovládací piny jako první multiplexer. Bude fungovat tak, že vypne kanál, který obsluhuje pin, ke kterému je multiplexováno. Tímto zajistíme pˇrepínání s použitím pouze jediného pinu, který bude sloužit k potlaˇcení této funkcionality, která by nám rozbila napˇetový dˇeliˇc a další funkce. Zjednodušené schéma tohoto systému pro 8 pin ˚u ZIF patice je znázornˇeno na obrázku 2.3. Tento obvod je na USP celkem 5 krát - pro každých 8 pin ˚u, a to podle stejné schématu jako zapojení p ˚uvodních multiplexer ˚u (obrázek 2.1). Kompletní zapojení toho obvodu je dostupné jako pˇríloha A.1.


Obrázek 2.3: Zjednodušené schéma obvodu pˇripojeného k 8 pin ˚um ZIF patice

Další komplikací spojenou s vyšším napˇetím je, že multiplexery a switche potˇrebují být ovládané tímto napˇetím. Nestaˇcí tedy již pˇripojit na ovládací pin multiplexeru/switche GPIO pin ˇrídícího mikrokontroléru, ale je nutné použít tranzistor a pullup/pulldown⁶
rezistor.

Poslední vˇecí, kterou musíme vyˇrešit, je kde získat napˇetí 12 volt ˚u. Jednou možností by bylo zapojit do USP pˇrímo toto napˇetí z externího zdroje, to by ale výraznˇe ztížilo jeho použití. Rozhodl jsem se proto pˇrímo do USP zabudovat step-up pˇrevodník, který nám vytvoˇrí napˇetí 12V. Obvod step-up pˇrevodníku byl navržen podle datasheetu regulátoru MC34063A [12]. Celé zapojení obvodu pˇrevodníku je zobrazeno v pˇríloze A.3.

5Z tohoto d ˚uvodu se použitý switch liší od switch ˚u [8], které používáme u zdroje multiplexeru.
6V závislosti na tom v jakém výchozím stavu chceme, aby byl ovládací pin; ve vˇetšinˇe pˇrípadu se bude jednat o pulldown rezistor.

Implementace

## 2.1.8 Dodateˇcný hardware

Krom výše uvedených souˇcástek a obvod ˚u, které slouží k zajištˇení detekce nebo nahrávání, je USP vybaven také 0.91” OLED displejem a ˇctyˇrmi tlaˇcítky. To umožní tvorbu uživatelského rozhraní pro jednodušší ovládání programátoru. OLED displej je také užiteˇcným nástrojem pro debugování. Dále jsou pak na programátoru tˇri LED - modrá, zelená a ˇcervená, které slouží pro optickou signalizaci stavu programátoru.

## 2.1.9 Využití pin ˚u

Nakonec se ukázalo, že 70 pin ˚u není až zase tolik a bylo nutné s nimi trochu šetˇrit. Následovat bude krátký pˇrehled toho, k ˇcemu bylo použito kolik pin ˚u a pˇrípadnˇe jakým zp ˚usobem byly piny uspoˇreny.

- 40 pin ˚u je nutných k obsloužení všech pin ˚u na ZIF patici.
- 5 pin ˚u s podporou ADC je pˇripojeno k pˇeti multiplexer ˚um.
- 3 piny jsou použity pro sdílenou kontrolu multiplexer ˚u na právé stranˇe ZIF patice (1, 2 a 3). 7
- 3 piny jsou použity pro sdílenou kontrolu multiplexer ˚u na levé stranˇe ZIF patice (4 a 5). 7
- 5 pin ˚u ovládá jestli je každý z pˇeti multiplexer ˚u pˇripojen k 12 volt ˚um nebo ADC pˇrevodníku.
- 1 pin ovládá zda switche odpojují piny, na které je právˇe multiplexováno, jak je popsáno v sekci 2.1.7.
- 2 piny jsou použity pro display.
- 4 piny jsou využívány tlaˇcítky.
- 3 piny ovládají LEDky.
- 2 piny jsou potˇreba pro sériovou komunikaci s poˇcítaˇcem.
- zbylé 2 piny jsou vyvedeny do headeru.

Celkem je tedy využito všech 70 dostupných pin ˚u.

## 2.1.10 Plošný spoj

Po otestování ˇcástí nˇekterých výše zmínˇených obvod ˚u na nepájivém poli bylo potˇreba vytvoˇrit návrh desky plošného spoje. Rozhodl jsem se rovnou pro 4-vrstvý plošný spoj, vzhledem k tomu, že jsem plánoval umístit co nejvíce souˇcástek na co nejmenší plochu a vrchní vrstva je tak prakticky celá pokryta ploškami pro kontakty souˇcástek. Prostˇrední dvˇe vrstvy jsou udˇelány jako tzv. plane, kde vˇetšina vrstvy zabírá jeden signál, zde konkrétnˇe zemˇe a napájení, a slouží pro snížení rušení na desce. Hotového zapojení plošného spoje je k nahlédnutí v pˇríloze A.4.

7Pro všechny funkce kromˇe rozpoznání VCC a GND (sekce 1.1.3) nám staˇcí vždy jen jeden pin pˇripojený k multiplexeru, ostatní multiplexery m ˚užeme ignorovat. Pro rozpoznání VCC a GND budeme potˇrebovat dva multiplexery, jeden pro vytvoˇrení malého napˇetí a druhý pro ˇctení ostatních pin ˚u. K tomu nám ale postaˇcí nezávisle ovládat multiplexery na jiných stranách ZIF patice, nebot’ díky rozložení multiplexer ˚u podle obrázku 2.1 bude mít i nejmenší možný ˇcip alespoˇn dva piny na r ˚uzných stranách.

Implementace

# 2.2 Software

Pˇrestože bylo cílem projektu vytvoˇrit co nejlepší hardwarový výrobek, je jeho nedílnou souˇcástí i software nutný k zprovoznˇení tohoto hardwaru. Nicménˇe ne všechny funkce implementované na hardwarové úrovni jsou využity ze strany softwaru.

## 2.2.1 Princip fungování

Po zapnutí USP detekuje vložení ˇcipu, který následnˇe identifikuje a data o nˇem pˇredá nahrávaˇci (více o nˇem v sekci 2.2.5). Nahrávaˇc pak vykonává pˇríkazy, které dostane po sériové lince a programuje vložený ˇcip, dokud uživatel nezmáˇckne resetovací tlaˇcítko. Princip fungování konkrétnˇe zachycuje obrázek 2.4.


Obrázek 2.4: Diagram USP

## 2.2.2 Nízkoúrov ˇnové funkce

Jako první bylo potˇreba implementovat funkce pro ovládání hardwaru - konkrétnˇe multiplexer ˚u, OLED displeje a tlaˇcítek. U tlaˇcítek staˇcilo implementovat tzv. debouncing, tedy brát tlaˇcítko jako stisknuté až tehdy, když se jeho stav po nˇejakou dobu nemˇení.

Pro práci s displejem jsem použil knihovnu od Adafruitu pro ovladaˇc SSD1306, kterým je displej vybaven. Pro pˇrevod obrázk ˚u a grafik na displej jsem využil aplikaci image2cpp [10]. Na displeji jsou implementovány pˇrevážnˇe debugovací funkce, které se však mohou hodit i bˇehem provozu zaˇrízení. Není totiž vylouˇcené, že mˇeˇrení, která bylo potˇreba nakalibrovat⁸
, se budou v urˇcitých

8Mˇeˇrení kapacity je kalibrované pomocí aditivní a multiplikativní konstanty, které byly nalezeny experimentálnˇe. Bez tˇechto úprav se kapacita na pinech výraznˇe lišila, pravdˇepodobnˇe z d ˚uvodu rozdílné délky spoj ˚u na PCB, pˇrípadnˇe jejich vystavení p ˚usobení jiných komponent.

Implementace

situacích chovat trochu jinak a bude nutné je kalibrovat znovu. Z tohoto d ˚uvodu jsou kalibraˇcní data uložena v pamˇeti EEPROM, aby je bylo možné mˇenit i bez flashování.

Pro zprovoznˇení multiplexer ˚u jsem použil návrhový vzor Composite, kdy každý z pˇeti multiplexer ˚u je instancí tˇrídy, která obstarává vnitˇrní mapování jeho ovládacích pin ˚u na výstup a další nastavení. Všechny multiplexery jsou pak spoleˇcnˇe ovládány pomocí jiné tˇrídy, která pozná, který multiplexer má použít.

## 2.2.3 Interface

Interface funguje jako prostˇredník mezi nízkoúrovˇnovými hardwarovými funkcemi a detektorem, kterým se bude zabývat následující sekce. Poskytuje funkce zmˇeˇrení kapacity ˇci napˇetí na pinu, pˇripojení napˇetí 0.5 voltu a další.

Mˇeˇrení kapacity bylo implementování s pˇresností, která umožˇnuje rozpoznání polohy speciálních pin ˚u. Prakticky mˇeˇrení probíhá tak, že pin nabíjíme pomocí napˇetí 0.5 volt ˚u po dobu 5 mikrosekund⁹
. Pak nabíjet pˇrestaneme a zmˇeˇríme napˇetí, které na pinu je. Samotné zmˇeˇrení napˇetí trvá nˇejaký ˇcas, bˇehem kterého se pin stihne ˇcásteˇcnˇe vybít. Zmˇeˇrené napˇetí je tedy zˇcásti dáno rychlostí nabíjení i rychlostí vybíjení. Tento zp ˚usob mˇeˇrení ukázal, že piny GND a VCC mají prakticky dvojnásobnou mˇernou kapacitu než normální piny. Pin RESET je také zajímavý. U nˇekterých ˇcip ˚u se z pohledu kapacity chová jako kdyby tam v ˚ubec nebyl. U jiných ˇcip ˚u má naopak kapacitu výraznˇe vyšší než normální piny. V obou situacích jsme schopni pin RESET rozpoznat jako speciální pin.

## 2.2.4 Detektor

Detektor implementuje vysokoúrovˇnovou detekci ˇcip ˚u. Jeho fungování je znázornˇeno na obrázku 2.5.

Jednou z d ˚uležitých funkcí je detekce speciálních pin ˚u. Pro každý pin vloženého ˇcipu vyˇcíslíme, jak moc se relativnˇe odlišuje od pr ˚umˇerné kapacity pin ˚u na daném ˇcipu. Toto ˇcíslo budeme pˇrenesenˇe brát jako pravdˇepodobnost, že pin je speciálním pinem. Pˇet pin ˚u¹⁰ s nejvˇetší pravdˇepodobností vybereme a budeme je dále identifikovat, jak zachycuje obrázek 2.6. Vzhledem k zjištˇením pˇri mˇe-ˇrení kapacity popsaných v sekci 2.2.3 by se mˇelo jednat, s danou pravdˇepodobností, o nˇekterý ze speciálních pin ˚u - tedy bud’ GND, VCC nebo RESET.

Cílem identifikace je rozpoznat, jestli je speciální pin GND. Ke pˇet nejpravdˇepodobnˇejším speciálním pin ˚um, které jsme vybrali, si doplníme informaci jestli jsou pinem GND. Pokud pin není GND, jedná se bud’ o VCC, RESET, nebo o pin, který byl chybnˇe detekován jako speciální (v takovém pˇrípadˇe by jeho pravdˇepodobnost, a tedy i vliv na výslednou volbu ˇcipu, mˇela být minimální).

Nakonec budeme iterovat pˇres všechny podporované ˇcipy dané velikosti a pro obˇe možná otoˇcení ˇcipu zjistíme, jestli jeho speciální piny sedí se speciálními piny, které jsme detekovali. Výsledná shoda ˇcipu je souˇcet pravdˇepodobností tˇechto shodných speciálních pin ˚u. Nejpravdˇepodobnˇejší

9Tato doba pˇri testování dávala nejlepší výsledky.
10Nejvyšší poˇcet speciálních pin ˚u, který m ˚uže AR ˇcip o maximální podporované velikosti, je 5, vˇcetnˇe RE-SETu, ale teoreticky ani ˇcip s více speciálními piny nebude problém detekovat, nebot’ i s pomocí pˇeti pin ˚u bychom ho mˇeli s jistotou urˇcit.

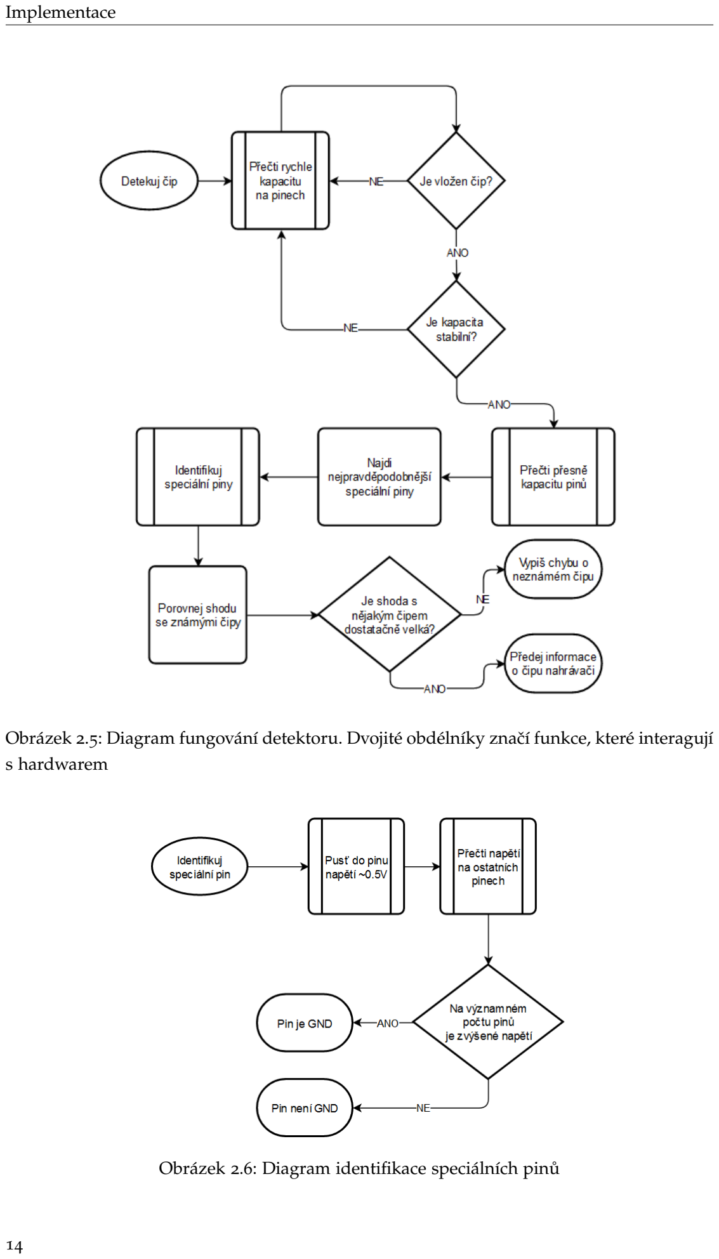
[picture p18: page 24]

Implementace

Obrázek 2.5: Diagram fungování detektoru. Dvojité obdélníky znaˇcí funkce, které interagují s hardwarem

Obrázek 2.6: Diagram identifikace speciálních pin ˚u

Implementace

ˇcip, který pˇrekonal stanovenou minimální shodu, je prohlášen za identifikovaný a informace o nˇem jsou pˇredány dále.

## 2.2.5 Nahrávaˇc

Díky detektoru ted’ víme, jaký ˇcip je vložen do patice, na jaké je pozici a jak je orientovaný. Víme tedy také, kde jsou umístˇeny piny, které potˇrebujeme pro nahrávání. Tyto informace již tedy staˇcí pˇredat nahrávaˇci. Pro zjednodušení jsem využil již implementovaný nahrávaˇc, Arduino ISP, který je distribuovaný s Arduino IDE. Tento nahrávaˇc jsem zvolil mimo jiné proto, že ho lze snadno ovládat právˇe z Arduino IDE a pˇri použití USP uživatelem tedy nebude nutné nic instalovat ani upravovat.

Do Arduino ISP jsem doimplementoval softwarový oscilátor pomocí hardwarového ˇcasovaˇce zabudovaného v ˇcipu ATmega2560 [2]. Díky tomu je možné programovat i ˇcipy, které vyžadují externí oscilátor.

Implementace nahrávaˇce je udˇelaná tak, aby ho v pˇrípadˇe potˇreby bylo možné snadno vymˇenit za jiný. To bude nutné tˇreba pro pˇridání podpory HVSP ˇci HVPP, nebot’ tyto protokoly Arduino ISP nepodporuje.

Implementace

# 3. Technická dokumentace

# 3.1 Použití

Univerzální sériový programátor nevyžaduje instalaci žádného dalšího programu pro použití. Z vnˇejšího pohledu se chová stejnˇe jako standardní Arduino ISP, které je široce podporované. Po zapojení do poˇcítaˇce pˇres USB type-B port, kterým je Arduino Mega vybaveno, m ˚uže chvíli (nˇekolik sekund) trvat, než se USP inicializuje a zahájí komunikaci s poˇcítaˇcem pˇres sériový port¹
. Poté, co
se na obrazovce USP objeví nápis ‘Ready’, je USP pˇripraven k vložení ˇcipu. Ten m ˚uže být vložen s libovolnou orientací a na libovolné místo. Aktuální verze USP podporuje prakticky všechny ˇcipy ˇrad Atmega a ATtiny v provedení DIP.²

Ihned po vložení ˇcipu a jeho zajištˇení páˇckou probíhá detekování. Bˇehem tohoto procesu se programátoru nedotýkejte, mohlo by to zp ˚usobit špatnou detekci ˇcipu. Po detekování se na displeji ukáže jméno detekovaného ˇcipu.³ V této chvíli je již možné do ˇcipu nahrávat stejným zp ˚usobem jako do normálního zaˇrízení Arduino ISP. Možné zp ˚usoby nahrávání do ˇcip ˚u pˇres USP si rozebereme v následujích sekcích.

Po vyndání ˇcipu je možné stiskem libovolného tlaˇcítka resetovat USP do p ˚uvodního stavu a pˇripravit ho na další ˇcip, který je možné vložit poté, co se na displeji objeví ‘Ready’.

## 3.1.1 Použití s Arduino IDE

Použití s Arduino IDE je pravdˇepodobnˇe nejjednodušší. Jako pˇríklad ˇreknˇeme, že chceme nahrát program do ˇcipu Atmega328P, který mimo jiné pohání Arduino Uno. Prvním krokem je zvolit Arduino ISP jako programátor pod Nástroje>Programátor>Arduino as ISP a zvolit Port do kterého je USP pˇripojen. V nabídce port ˚u se bude USP ukazovat pod jménem Arduino Mega. Dalším krokem je zvolit ˇcip, do kterého budeme nahrávat v Nástroje>Vývojová deska. V našem pˇríkladˇe to bude ‘Arduino Uno’, pod ˇcímž se skrývá ˇcip Atmega328 nastavený na použití externího oscilátoru s frekvencí 16Mhz, který je na desce Arduino Uno. Toto nastavení, se zvýraznˇenými d ˚uležitými parametry, je na obrázku 3.1.

Nahrávání do jiných mikrokontrolér ˚u, kterými nejsou obsazeny desky Arduino, vyžaduje stažení pˇríslušných knihoven. Pro ˇcipy ATtiny m ˚uže být použita napˇríklad knihovna ATTinyCore [9]. Po jejím nainstalování se nám pˇríslušné mikrokontroléry ukáží pod Nástroje>Vývojová deska a bude pro nˇe dostupné více nastavení. Možná nastavení, která nemusí být dostupná pro každý mikrokontrolér, jsou BOD (Brown-out detection; napˇetí, pˇri kterém se ˇcip vypnˇe), ˇcíslování pin ˚u, hodiny (vnitˇrní/vnˇejší oscilátor a jeho frekvence) a mnoho dalšího. Pˇríklad nastavení pro programování ˇcipu ATtiny84 s interním oscilátorem 8Mhz je na obrázku 3.2.

1Ke komunikaci je nutné mít ovladaˇce, ty se ale nainstalují samy pˇri instalaci Arduina IDE, AVRDUDE nebo podobných program ˚u.
2Fyzicky jsem však testoval jen dva r ˚uzné ˇcipy ATtiny a jeden ATmega, takže je možné, že pro urˇcité specifické ˇcipy bude potˇreba upravit parametry v kódu a ten flashovat do USP, více o tom v sekci 3.2.

3
Jméno na displeji se m ˚uže lišit od reálného použitého ˇcipu, nebot’ existuje mnoho variant ˇcip ˚u se stejným rozložením. Na displeji je zobrazeno jméno nejznámnˇejšího ˇcipu s daným rozložením nebo ˇcipu s nejvˇetší pamˇetí.

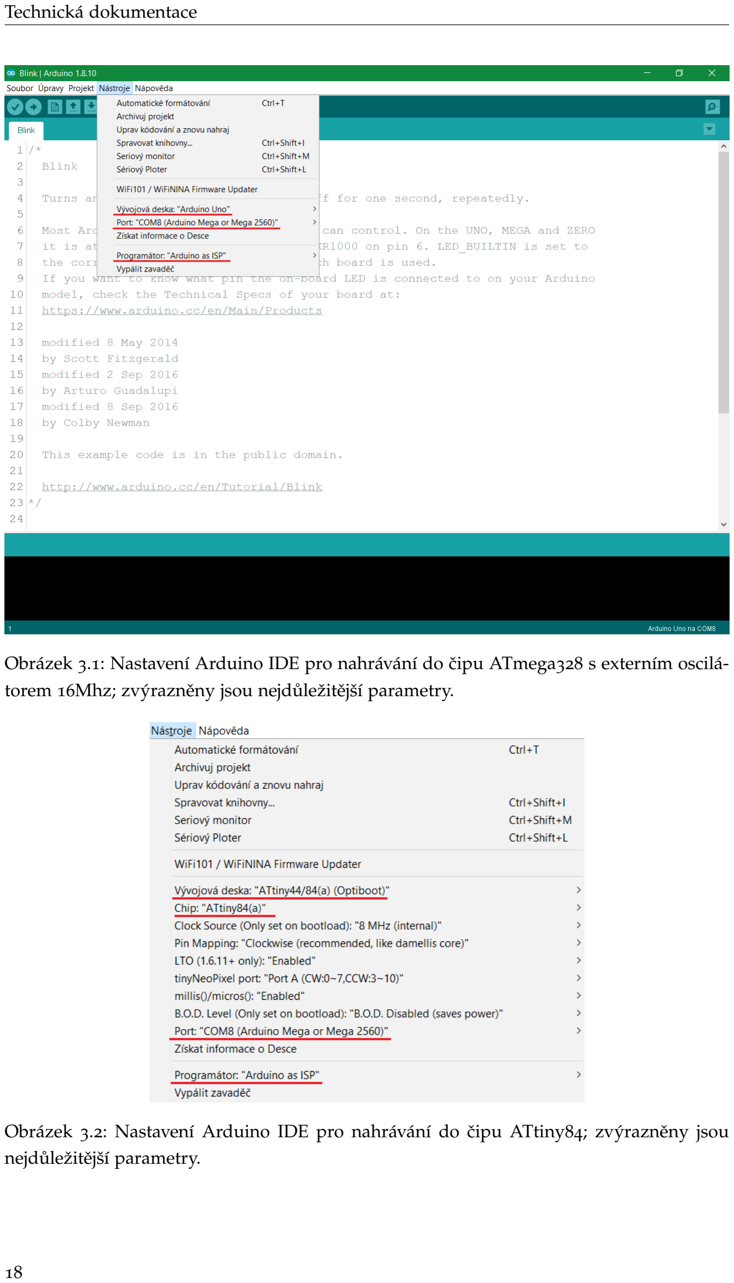
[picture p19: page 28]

Technická dokumentace

Obrázek 3.1: Nastavení Arduino IDE pro nahrávání do ˇcipu ATmega328 s externím oscilátorem 16Mhz; zvýraznˇeny jsou nejd ˚uležitˇejší parametry.

Obrázek 3.2: Nastavení Arduino IDE pro nahrávání do ˇcipu ATtiny84; zvýraznˇeny jsou nejd ˚uležitˇejší parametry.

Technická dokumentace

V pˇrípadˇe, že je toto první nahrávání do konkrétního ˇcipu bude potˇreba vypálit bootloader. To lze v Arduino IDE udˇelat pod Nástroje>Vypálit zavadˇeˇc. Tím se pˇríslušné parametry, jako frekvence oscilátoru ˇci BOD, vypálí do mikrokontroléru. Poté je již možné nahrávat program do ˇcipu pod Projekt>Nahrát pomocí programátoru nebo pomocí zkratky Ctrl+Shift+U.

Mikrokontrolér, do kterého jsme nahrávali kód pomocí programátoru, nebude následnˇe možné programovat pomocí sériového portu. Tento zp ˚usob programování je využíván napˇríklad pˇri bˇezném nahrávání do desek Arduino Uno. Pokud tedy chceme ˇcip vložit do desky Arduino Uno nebo podobné, bude nutné znovu vypálit bootloader pod Nástroje>Vypálit zavadˇeˇc. Poté již do ˇcipu nenahrávejte s pomocí USP a vložte jej do desky Arduino Uno.

## 3.1.2 Použití s AVRDUDE


Obrázek 3.3: Nastavení AVRDUDESS pro nahrávání do ˇcipu Attiny84, zvýraznˇeny jsou nejd ˚uležitˇejší parametry.

Podobnˇe jako s Arduino IDE, lze nahrávat i programem AVRDUDE, pˇrípadnˇe s použitím UI verze zvané AVRDUDESS. Opˇet je nutné pouze zvolit port, programátor Arduino, cílový ˇcip a tentokrát i rychlost komunikace 19200 baud ˚u. Nastavení pro ATtiny84 je dostupné na obrázku 3.3. Hlavní výhodou AVRDUDE je, že pomocí nˇej jsme schopni nastavovat a ˇcíst fuse bits, ˇcíst a zapisovat do

Technická dokumentace

EEPROM ˇci flash pamˇeti ˇci nastavovat lock bits. Lze pomocí nˇej do urˇcité míry oživovat i zdánlivˇe mrtvé ˇcipy.

# 3.2 Nahrávání od USP

Deska USP chrání ˇrídící mikroprocesor na Arduino Mega proti nechtˇenému flashování. V pˇrípadˇe, že bude potˇreba do nˇej nahrávat, je nutné nejdˇríve odstranit žlutý jumper s oznaˇcením ‘self prog’, který se nachází na druhé stranˇe desky než displej a tlaˇcítka. Poté bude již možné nahrávat do Arduino Mega standardním zp ˚usobem.

# Závˇer

Hlavním cílem projektu bylo vytvoˇrit hardwarový výrobek, který bude reálnˇe užiteˇcný a výraznˇe zjednodušší nahrávání do (pˇrevážnˇe) AVR ˇcip ˚u v pouzdˇre DIP. Tento cíl projekt splnil. Na hardwarové úrovni bylo implementováno i nˇekolik bonusových funkcí, jako napˇríklad podpora vysokonapˇet’ového programování, které pouze ˇcekají na implementaci v softwaru.

Zaˇrízení je funkˇcní a bylo otestováno na nˇekolika mikrokontrolérech, které jsem mˇel k dispozici. Jeho spolehlivost by bylo možné dále zvýšit d ˚ukladnˇejším testování na dalších ˇcipech a doladˇením parametr ˚u detekce. Také by bylo možné vytvoˇrit uživatelsky pˇrívˇetivé rozhraní, které by umožˇnovalo napˇríklad volbu nahrávacího protokolu, pˇrípadnˇe poskytovalo nˇekteré funkce i bez pˇripojení k poˇcítaˇci, k ˇcemuž je také pˇripraven potˇrebný hardware.

Bˇehem práce na projektu jsem se toho mnoho nauˇcil nejen o AVR ˇcipech a CMOS obvodech, které jsem využíval, ale také o elektrotechnice obecnˇe. Získal jsem cenné zkušeností pˇri návrhu plošného spoje, výbˇeru potˇrebných komponent a zkoumání jejich vzájemných interakcí.

# Seznam použité literatury

[1] Arduino. Arduino Mega. url: https://www.arduino.cc/en/pmwiki.php?n=Main/

ArduinoBoardMega (https://www.arduino.cc/en/pmwiki.php?n=Main/ArduinoBoardMega) (cit. 15. 03. 2022).
[2] Atmel. 8-bit Atmel Microcontroller with 16/32/64KB In-System Programmable Flash. Atmel
ATmega640/V-1280/V-1281/V-2560/V-2561/V. Datasheet 2549Q–AVR–02/2014.

## [3] Atmel. 8-bit AVR Microcontroller with 2/4/8K Bytes In-System Programmable Flash. AT-

tiny24/44/84. Datasheet 8006K–AVR–10/10.

## [4] Atmel. 8-bit AVR Microcontroller with 32K Bytes In-System Programmable Flash. AT-

mega328P. Datasheet 7810D-AVR-01/15.
[5] Atmel. Atmel 8-bit AVR Microcontroller with 2/4/8K Bytes In-System Programmable Flash.
ATtiny25/V / ATtiny45/V / ATtiny85/V. Datasheet 2586Q-AVR-08/2013.
[6] Atmel. megaAVR ® Data Sheet. ATmega32A. Datasheet DS40002072A, Rev. 2018.

## [7] Texas Instruments. CD405xB CMOS Single 8-Channel Analog Multiplexer/Demultiplexer

with Logic-Level Conversion. CD4051B. Datasheet SCHS047I, Rev. 2017.

[8] Texas Instruments. CD4066B CMOS Quad Bilateral Switch. CD4066B. Datasheet SCHS051H, Rev. 2020.
[9] Spence Konde. ATTinyCore. url: https://github.com/SpenceKonde/ATTinyCore
(cit. 17. 03. 2022).
[10] Jasper van Loenen. image2cpp. url: https : / / javl . github . io / image2cpp/ (https://javl.github.io/image2cpp/) (cit.
17. 03. 2022).
[11] Matthias Neeracher. ScratchMonkey - Overview. 2016. url: https://microtherion.

github.io/ScratchMonkey/Overview.html (https://microtherion.github.io/ScratchMonkey/Overview.html) (cit. 14. 03. 2022).
[12] ON Semiconductor. 1.5 A, Step-Up/Down/ Inverting Switching Regulators. MC34063A.
Datasheet MC34063A/D, Rev. 2010.
[13] ON Semiconductor. Quad Analog Switch/Quad Multiplexer. MC14066B. Datasheet SCHS047I, Rev. 2017.

# Seznam obrázk ˚u

1.1 | Schéma vnitˇrního zapojení IO pinu mikrokontroléru [4, str. 58] | | 5
2.1 | Schéma zapojení mulitplexer ˚u k pin ˚um ZIF patice | | 8
2.2 | Schéma dˇeliˇce napˇetí | | 9
2.3 | Zjednodušené schéma obvodu pˇripojeného k 8 pin ˚um ZIF patice | | 10
2.4 | Diagram USP | | 12
2.5 | Diagram fungování detektoru. Dvojité obdélníky znaˇcí funkce, které interagují s hard-
| warem | | 14
2.6 | Diagram identifikace speciálních pin ˚u | | 14
3.1 | Nastavení Arduino IDE pro nahrávání do ˇcipu ATmega328 s externím oscilátorem 16Mhz;
| zvýraznˇeny jsou nejd ˚uležitˇejší parametry | | 18
3.2 | Nastavení Arduino IDE pro nahrávání do ˇcipu ATtiny84; zvýraznˇeny jsou nejd ˚uležitˇejší
| parametry | | 18
3.3 | Nastavení AVRDUDESS pro nahrávání do ˇcipu Attiny84, zvýraznˇeny jsou nejd ˚uležitˇejší
| parametry | | 19
A.1 | Úplné schéma obvodu pˇripojeného k 8 pin ˚um ZIF patice | | 29
A.2 | Úplné schéma zapojení switche, který pˇrepíná vstup do multiplexer ˚u 1 a 2 mezi ADC
| pinem a 12V | | 30
A.3 | Úplné schéma obvodu step-up pˇrevodníku z 5 na 12 volt ˚u. Obvod zahrnuje nula ohmové
| odpory a solder jumper, které umožˇnují jednoduché odpojení pˇrevodníku | | 31
A.4 | Zapojení plošného spoje. Žlutou barvou jsou vyznaˇceny spoje ve vrchní vrstvˇe, zelenou
| spoje spodní vrstvy a ˇcervenou spoje jedné z vnitˇrních vrstev. Druhá vnitˇrní vrstva není
| na obrázku zachycena | | 32

# Pˇrílohy


Obrázek A.1: Úplné schéma obvodu pˇripojeného k 8 pin ˚um ZIF patice.

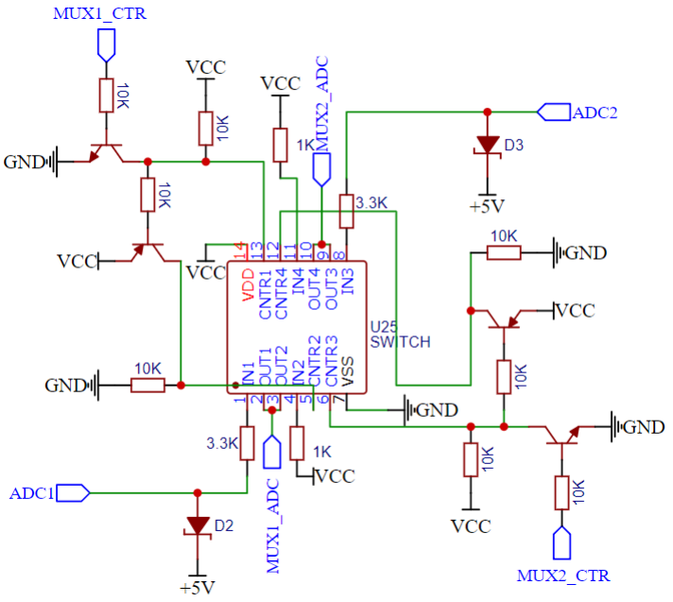
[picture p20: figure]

Obrázek A.2: Úplné schéma zapojení switche, který pˇrepíná vstup do multiplexer ˚u 1 a 2 mezi ADC pinem a 12V.

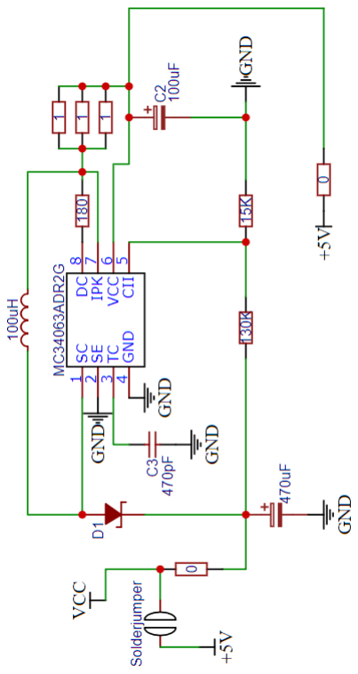
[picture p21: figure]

Obrázek A.3: Úplné schéma obvodu step-up pˇrevodníku z 5 na 12 volt ˚u. Obvod zahrnuje nula ohmové odpory a solder jumper, které umožˇnují jednoduché odpojení pˇrevodníku.

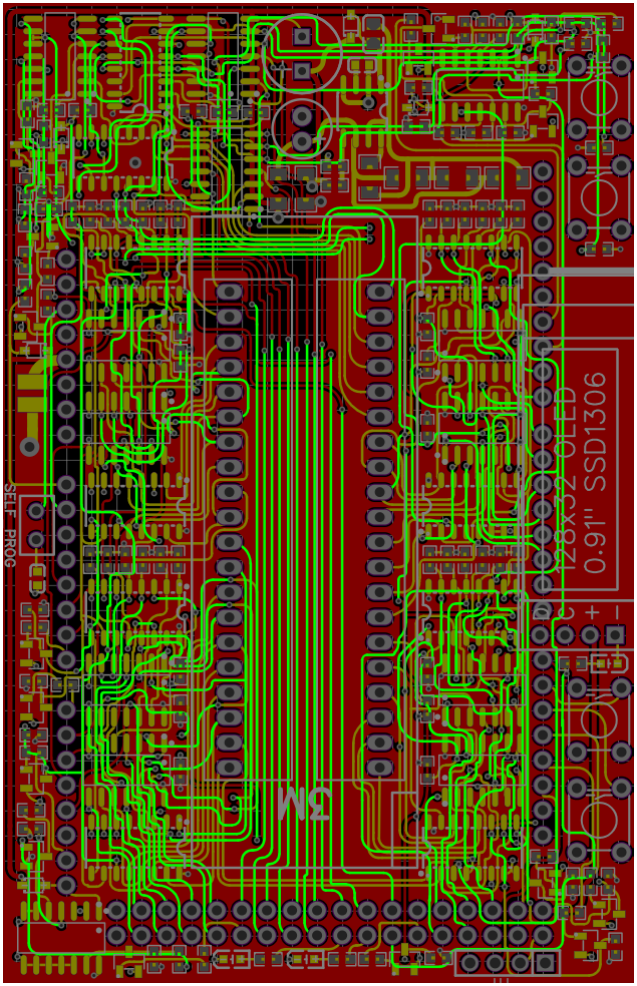
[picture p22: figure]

Obrázek A.4: Zapojení plošného spoje. Žlutou barvou jsou vyznaˇceny spoje ve vrchní vrstvˇe, zelenou spoje spodní vrstvy a ˇcervenou spoje jedné z vnitˇrních vrstev. Druhá vnitˇrní vrstva není na obrázku zachycena.

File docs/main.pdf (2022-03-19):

# GYMNASIUM JANA KEPLERA

### Parléˇrova 2/118, 169 00 Praha 6


# Univerzální sériový programátor

# Maturitní práce

### Autor: Petr Šícho

### Tˇrída: R8.A

### Školní rok: 2021/2022

### Pˇredmˇet: Informatika

### Vedoucí práce: Bc. Emil Miler

### Praha, 25.3.2022

# GYMNASIUM JANA KEPLERA Kabinet informatiky

# ZADÁNÍ MATURITNÍ PRÁCE

Student: | Petr Šícho
Tˇrída: | R8.A
Školní rok: | 2021/2022
Platnost zadání: | 30. 9. 2022
Vedoucí práce: | Emil Miller
Název práce: | Univerzální sériový programátor

Pokyny pro vypracování: Cílem práce je vymyslet a vytvoˇrit univerzální programátor minimálnˇe pro nejznámnˇejší ˇcipy AVR, tedy ˇrady Attiny a Atmega. Univerzální programátor má ulehˇcit nahrávání do zmínˇených ˇcíp ˚u, bez nutnosti zapojovat cokoliv na nepájivém poli. Programátor by mˇel detekovat jaký je do nˇej vložený ˇcip a umožnit do nˇej nahrávat z poˇcítaˇce. Za dodateˇcné, vedlejší, funkce by se dalo napˇríklad považovat možnost nahrávat do ˇcip ˚u pˇres pin header, tedy bez vyndavání ˇcipu z postaveného obvodu. Výsledkem projektu by minimálnˇe mˇel být funkˇcní

prototyp programátoru, který je použitelný pro specifikovaný úˇcel.

## Doporuˇcená literatura: Zde bude vedoucím práce doplnˇena literatura, ze které je doporuˇceno pˇri práci

na tématu vycházet.

## URL repozitáˇre:

## https://github.com/Xmen097/USP

student | vedoucí práce

## V Praze dne 19. 10. 2021

# Prohlášení

Prohlašuji, že jsem svou práci vypracoval samostatnˇe a použil jsem pouze prameny a literaturu uvedené v seznamu bibliografických záznam ˚u. Nemám žádné námitky proti zpˇrístupˇnování této práce v souladu se zákonem ˇc. 121/2000 Sb. o právu autorském, o právech souvisejících s právem autorským a o zmˇenˇe nˇekterých zákon ˚u (autorský zákon) ve znˇení pozdˇejších pˇredpis ˚u.

V Praze dne 19. bˇrezna 2022 | Petr Šícho

# Podˇekování

Chtˇel bych podˇekovat pˇredevším open hardware komunitˇe, specificky pak Arduino komunitˇe, na jejíž fórem jsem našel znaˇcné množství informací. Dále dˇekuji Bc. Emilovi Milerovi za pomoc pˇri vedení této maturitní práce.

# Abstrakt

Tato maturitní práce si klade za cíl zjednodušit proces programování a nahrávání do mikrokontrolér ˚u v pozdˇre DIP. Univerzální sériový programátor (USP), který v rámci této práce vznikl, je zaˇrízení, které je schopné automaticky detekovat rozložení vývod ˚u ˇcipu vloženého do ZIF patice. Na základˇe toho rozpozná o který ˇcip se jedná a uzp ˚usobí pro nˇej nahrávací obvod. Teoreticky by mˇel USP umˇet programovat všechny ˇcipy pracující na 5 voltech a podporovat dostateˇcnˇe pomalé bit-banging programovací protokoly, vˇcetnˇe tˇech, které vyžadují vysoké napˇetí (12V) pro resetování. Na softwarové úrovni aktuálnˇe USP pracuje na protokolu Arduino ISP.

## Klíˇcová slova

programátor, ˇcip, AVR, nahrávaˇc, USP

# Abstract

Abstract.

## Keywords

programmer, chip, AVR, uploader, USP

# Obsah

1 Teoretická ˇcást | 3
2 Implementace | 7
2.1.2 | Rídící mikroprocesor | ˇ | 7
3 Technická dokumentace | 17
Závˇer | 21
Seznam použité literatury | 23
Seznam obrázk ˚u | 25

# 1. Teoretická ˇcást

Existuje nepˇreberné množství r ˚uzných ˇcip ˚u a s nimi podobné množství r ˚uzných rozložení vývod ˚u, které nejsou jednotné ani u jedné velikosti a jednoho výrobce. Pro každé rozložení je nutné mít externí nahrávací obvod. Cílem práce je sjednotit tyto nahrávací obvody do jednoho univerzálního, který se pˇrizp ˚usobí vloženému ˇcipu. Fungování programátoru lze rozdˇelit na dvˇe ˇcásti - nejdˇrív je nutné detekovat ˇcip a poté je potˇreba do nˇej nahrávat.

Pro univerzální programátor není možné použít žádný dedikovaný hardware, který by zajišt’oval nahrávání. Naopak se nám hodí použít univerzálních vstupních / výstupních pin ˚u neboli GPIO¹ pin ˚u. I pˇres snahu o maximální univerzálnost není reálné docílit podpory úplnˇe všech existujících ˇcip ˚u. Jako minimální požadovanou funkcionalitu jsem tedy bral podporu ˇcip ˚u AVR od výrobce Atmel, konkrétnˇe pak ˇrady ATmegy a ATtiny, které zahrnují ˇcipy, jež pohání známé desky Arduino. Pˇresto doufám, že vlastnosti tˇechto ˇcip ˚u, na kterých je detekce a nahrávání postaveno, budou do velké míry pˇrenositelné i na jiné rodiny ˇci výrobce ˇcip ˚u.

# 1.1 Detekce

Základem detekce je poznat jak velký ˇcip je - tedy kolik má vývod ˚u. Jen díky tomu se nám radikálnˇe sníží poˇcet možných kandidát ˚u. Pˇri zahrnutí jen nˇekolika model ˚u, jednoho pro každou velikost, bychom tak mˇeli prakticky hotovo. Bylo by však nutné arbitrárnˇe stanovit tyto podporované ˇcipy, pˇriˇcemž pˇri vložení jiného, at’ tˇreba ze stejné rodiny, který má prohozené piny GND a VCC, by došlo pravdˇepodobnˇe k jeho zniˇcení. Naší ambicí tedy bude zjistit o ˇcipu co nejvíce informací, díky nimž budeme schopni rozeznávat mezi co nejvˇetším poˇctem r ˚uzných ˇcip ˚u.

Pˇri detekci se musíme dávat pozor, abychom náhodou ˇcip nepoškodili. Ideálnˇe bychom se chtˇeli držet v hodnotách, které povoluje datasheet. Problém je, že to, o co se pokoušíme, není standardní zacházení s ˇcipy a v datasheetu tak nenalezneme konkrétní povolené hodnoty a situace, kterým m ˚užeme ˇcip bezpeˇcnˇe vystavit. M ˚užeme pomocí nˇej alespoˇn odhadnout nˇekteré základní principy, kterých když se budeme držet, tak minimalizovali poškození ˇcipu. Konkrétnˇe se jedná o:

- Nevystavovat žádný pin napˇetí nižšímu než −0.5V
- Nevystavovat žádný pin, kromˇe RESETu, napˇetí vyššímu než Vcc + 0.5V
- Nevystavovat RESET napˇetí vyššímu než 13V
- Nenechat mezi žádný dvˇema piny nezapojeného ˇcipu téct nezanedbatelnˇe velký proud po nezanedbatelnˇe dlouhou dobu 2

Pˇri splnˇení tˇechto podmínek by mˇel být ˇcip dostateˇcnˇe chránˇen obvody, které bˇežnˇe slouží k ochranˇe pˇred elektrostatickým výbojem (ESD).

1z anglického General-purpose input/output, tedy pin, který se umí chovat bud’ jako digitální vstup, nebo výstup, pˇriˇcemž mezi tˇemito módy je možné pˇrepínat.
2Pro naše úˇcely budeme považovat za zanedbatelný proud ˇrádu mikroampér a ˇcas mikrosekund.

Teoretická ˇcást

## 1.1.1 Detekce velikosti a polohy

Pro detekci velikosti ˇcipu m ˚užeme využít toho, že každá reálná souˇcástka, kromˇe svých primárních vlastností, vykazuje také elektrickou kapacitu. To bude jistˇe platit i pro spoje a souˇcástky uvnitˇr integrovaných obvod ˚u. Elektrická kapacita pin ˚u jednoduchých CMOS³
ˇcip ˚u[5, 6, 11] se pohybuje v jednotách pikofarad ˚u, což není mnoho. Není mi znám žádný zp ˚usob pˇrímého mˇeˇrení elektrické kapacity, budeme tedy muset provést mˇeˇrení nepˇrímé a dostateˇcnˇe pˇresné. Jednou z možností je kapacitor pomalu nabíjet nebo vybíjet a mˇeˇrit ˇcas, který k tomu budeme potˇrebovat. Zkusíme odhadnout jak pˇresné takové mˇeˇrení bude s pomocí rovnice definující energii elektrického kondenzátoru

E =

1

2

CU²
(1.1)

Budeme-li kapacitor nabíjet napˇetím U a proudem I po dobu t, m ˚užeme psát

Wmax = U ·I· t | (1.2)

Jedná se o horní odhad vykonané práce, která poˇcítá s nulovým odporem a nulovým elektrickým potenciálem kapacitoru. Reálná energie pˇredaná kapacitoru bude nižší, což nám však nevadí. Úpravou tˇechto dvou vztah ˚u m ˚užeme vyvodit úmˇernost

C ≃ t/R | (1.3)

Zjistili jsme, že kapacita je pˇrímo úmˇerná ˇcasu, po který jsme kapacitor nabíjeli, a nepˇrímo úmˇerná odporu, pˇres který jsme nabíjeli.⁴ Cas budeme schopni mˇeˇrit velice pˇresnˇe, ˇrádovˇe v mikrosekund- ˇ nách (10−6

s). Reknˇeme, že pin ˇcipu má kapacitu ˇ | 10pF = 10−11F. Dosazením do vztahu (1.3) zjistíme,
že k jejímu zmˇeˇrení budeme potˇrebovat nabíjecí odpor o velikosti 100kΩ. To nebude problém, mˇe-ˇrení vypadá proveditelnˇe.

Díky schopnosti zmˇeˇrit kapacitu na každém z pin ˚u socketu zjistíme nejenom jak velký ˇcip je, ale zároveˇn i kde v socketu je vložen. Není tedy nutné nijak specifikovat na jakou pozici v socketu má být ˇcip pro nahrávání vložen.

## 1.1.2 Detekce speciálních pin ˚u

Každý mikrokontrolér má kromˇe vstupních / výstupních pin ˚u i speciální piny, které plní nˇejakou zvláštní funkci. Napˇríklad je to RESET pin, napájecí piny (GND a VCC) nebo piny hodin (XTAL). Tyto piny by mohly vykazovat rozdílné elektrické vlastnosti a možná i rozdílnou kapacitu. Nejvˇetší nadˇeji vkládám do napájecích pin ˚u, které jsou vnitˇrnˇe pˇripojené k všemožným souˇcástem mikrokontroléru a oˇcekávám u nich vyšší kapacitu. Pˇri dostateˇcnˇe pˇresném mˇeˇrení kapacity bychom ji mohli detekovat a urˇcit tak napájecí piny.

## 1.1.3 Rozpoznání VCC od GND

Pˇri špatném rozpoznání vloženého mikrokontroléru m ˚uže nejvˇetší poškození zp ˚usobit pˇrevrácení pin ˚u GND a VCC. Abychom se tohoto rizika vyvarovali, bylo by dobré rozpoznávat s jistotou VCC od GND. Tím zároveˇn obecnˇe snížíme šanci na špatné rozpoznání ˇcipu.

3Complementary metal-oxide semiconductor; technologie výroby integrovaných obvod ˚u
4Ke stejnému výsledku bychom došli i použitím rozmˇerové analýzy.

Teoretická ˇcást

Využijeme ochranných diod, které jsou pˇripojeny ke každému IO pinu mikrokontroléru, jak ukazuje obrázek 1.1. Povšimnˇeme si, že dioda spojující pin s GND smˇeˇruje opaˇcnˇe, než dioda spojující pin s VCC. Díky tomu bychom mˇeli být schopni rozpoznat, zda je urˇcitý pin GND ˇci VCC.


Obrázek 1.1: Schéma vnitˇrního zapojení IO pinu mikrokontroléru.[3, str. 58]

Pin GND m ˚užeme detekovat následovnˇe. Budeme znát úbytek napˇetí na diodˇe mezi pinem a GND Ud. Pˇrivedeme-li na pin GND napˇetí U pˇrevyšující Ud, mˇeli bychom na všech IO pinech detekovat napˇetí U − Ud. Z bezpeˇcnostních d ˚uvod ˚u by napˇetí U by mˇelo být co nejmenší možné, ideálnˇe U < 0.5V. Napˇetí pˇrivedeme pˇres dostateˇcnˇe velký odpor tak, aby mikrokontrolérem a diodou tekl co nejmenší proud. S malým procházejícím proudem budeme mít také menší úbytek napˇetí na diodˇe (menší, než bˇežnˇe udávaných ∼ 0.7V a snad i menší než 0.5V)

Obdobným zp ˚usobem je možné detekovat pin VCC. Staˇcí na libovolný (nebo lépe postupnˇe na všechny) IO pin pˇrivést napˇetí U a na pinu VCC by se nám vždy mˇelo ukázat napˇetí U − Ud.
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

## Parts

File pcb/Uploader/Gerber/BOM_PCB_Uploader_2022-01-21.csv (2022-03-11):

ID | Name | Designator | Footprint | Quantity | Manufacturer Part | Manufacturer | Supplier | Supplier Part | Price
1 | 19-217/BHC-ZL1M2RY/3T | LEDB | LED0603-R-RD_BLUE | 1 | 19-217/BHC-ZL1M2RY/3T | EVERLIGHT | LCSC | C72041 | 0.018
2 | 19-217/GHC-YR1S2/3T | LEDG | LED0603-R-RD | 1 | 19-217/GHC-YR1S2/3T | EVERLIGHT | LCSC | C72043 | 0.03
3 | KT-0603R | LEDR | LED0603-R-RD | 1 | KT-0603R | KENTO | LCSC | C2286
4 | 3.3K | R5,R6,R18,R59,R60,R76,R101 | R0603_NEW | 7 | 0603WAF3301T5E | UniOhm | LCSC | C22978 | 0.001
5 | MMBT3904-C20526 | Q15,Q1,Q3,Q4,Q5,Q9,Q10,Q11,Q7,Q13,Q17,Q12 | SOT-23-3_L2.9-W1.3-P1.90-LS2.4-BR | 12 | MMBT3904 | CJ | LCSC | C20526 | 0.015
6 | 10K | R90,R96,R63,R64,R65,R66,R67,R68,R69,R70,R71,R72,R77,R78,R79,R80,R81,R82,R83,R84,R85,R86,R55,R56,R57,R58,R73,R74,R75,R88,R97,R98,R99,R100 | R0603 | 34 | 0603WAF1002T5E | UniOhm | LCSC | C25804 | 0.001
7 | 1N5819WS | D2,D3,D4,D5,D6,D1 | SOD-323_L1.8-W1.3-LS2.5-RD | 6 | 1N5819WS | Guangdong Hottech | LCSC | C191023
8 | S9012 2T1 | Q2,Q8,Q6,Q14,Q18 | SOT-23-3_L2.9-W1.3-P1.90-LS2.4-BR | 5 | S9012 2T1 | CJ | LCSC | C8543 | 0.019
9 | 15K | R20,R21,R22,R23,R24,R26,R28,R29,R30,R31,R32,R33,R34,R35,R38,R39,R40,R41,R42,R43,R44,R45,R46,R47,R48,R49,R50,R51,R52,R53,R3,R9,R10,R11,R12,R13,R14,R15,R16,R25,R27 | R0603 | 41 | 0603WAF1502T5E | UniOhm | LCSC | C22809 | 0.001
10 | SWITCH | U8,U9,U14,U15,U16,U17,U22,U23,U1,U7,U25,U24,U26 | SOP-14_L8.6-W3.9-P1.27-LS6.0-BL | 13 | MC14066BDR2G | ON | LCSC | C52828 | 0.336
11 | MULTIPLEXER | U10,U11,U12,U13,U18,U19,U20,U21,U2,U6 | SOP-16_L9.9-W3.9-P1.27-LS6.1-BL | 10 | CD4051BM/TR | HGSEMI | LCSC | C507163 | 0.126
12 | 1K | R36,R37,R54,R17,R19,R61,R62,R87,R89,R91 | R0603 | 10 | 0603WAF1001T5E | UniOhm | LCSC | C21190 | 0.001
13 | 470pF | C3 | C0603 | 1 | 0603B471K500NT | FH | LCSC | C1620 | 0.003
14 | 100nF | C4 | C0603 | 1 | CC0603KRX7R9BB104 | YAGEO | LCSC | C14663 | 0.003
15 | 100uH | L1 | L0805 | 1 | MLF2012C101KT000 | TDK | LCSC | C68035 | 0.062
16 | 180 | R1 | R1206 | 1 | 1206W4F1800T5E | UniOhm | LCSC | C17924 | 0.004
17 | 1 | R2,R7,R8 | R1206 | 3 | 1206W4F100KT5E | UniOhm | LCSC | C17928 | 0.006
18 | 130K | R4 | R0603 | 1 | 0603WAF1303T5E | UniOhm | LCSC | C22795 | 0.001
19 | MC34063ADR2G | U3 | SOIC-8_L5.0-W4.0-P1.27-LS6.0-BL | 1 | MC34063ADR2G | ON | LCSC | C32078 | 0.405
20 | 0 | R92,R93 | R1206 | 2 | 1206W4F0000T5E | UniOhm | LCSC | C17888 | 0.004

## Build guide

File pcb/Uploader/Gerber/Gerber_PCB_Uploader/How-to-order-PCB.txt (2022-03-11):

How to Order PCB

Please refer to:
https://docs.easyeda.com/en/PCB/Order-PCB

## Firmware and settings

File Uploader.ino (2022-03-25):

#include "src/hardware/input.h"
#include "src/hardware/display.h"
#include "src/app/detector.h"
#include "src/utils/debug.h"
#include "src/utils/ISP.h"

#define BAUDRATE  19200
// #define BAUDRATE 115200
// #define BAUDRATE 1000000

void setup() {
    Display::setup();
    Detector::setup();
    Input::setup();
    Serial.begin(BAUDRATE);
    pinMode(LEDG, OUTPUT);
    pinMode(LEDB, OUTPUT);
    pinMode(LEDR, OUTPUT);
    digitalWrite(LEDG, HIGH);
    delay(500);
}

void loop() {
    Display::write(F("Ready"));
    while(!Detector::is_detected());
    Display::write(F("Detecting"));
    Detector::identify_chip();
    Display::write(Detector::detected_chip.name);
    if (Detector::detected_chip != UnknownChip) {
        Detector::power_up();
        ISP::setup();   
        Input::loop();
        while(!Input::is_down(Button::ANY)) {
            Input::loop();
            ISP::loop();
        }
        Detector::power_down();
    } else {
        Input::wait_until(Button:ANY);
    }
}

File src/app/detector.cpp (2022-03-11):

#include "detector.h"

namespace Detector {

    uint8_t low_reset = 255;
    uint8_t chip_start = 255;
    uint8_t chip_end = 0;
    uint8_t chip_size = 0;
    bool rotated = false;
    Chip detected_chip = UnknownChip;


    void setup() {
        Interface::setup();
    }

    uint8_t chip_inserted(uint16_t* data) {
        chip_start = 255;
        chip_end = 0;
        low_reset = 255;
        rotated = false;
        detected_chip = UnknownChip;
        bool low_pin = false;
        bool result = true;
        for (int i=0; i<20; i++) {
            if (data[i]+data[39-i] < 50)
                continue;
            if (min(data[i], data[39-i]) < 50) {
                if (low_pin)
                    return 0;
                else
                    low_pin = true;
            } else if (chip_start != 255 && i - chip_end > 1)
                return 0;
            
            chip_start = min(chip_start, i);
            chip_end = max(chip_end, i);
        }
        chip_size = chip_end-chip_start+1;
        
        return (chip_size >= 4);
    }

    bool stable(uint16_t* data) {
        const uint8_t history = 5;
        const uint8_t relative_treshold = 25;
        const uint8_t absolute_treshold = 5;
        const uint16_t time_treshold = 10000;

        static uint16_t last_matrix[40*history] = {0};
        static uint32_t last_time[history] = {0};
        static uint8_t ptr = 0;

        bool response = true;

        last_time[ptr] = millis();
        for (int i=0; i<40; i++) {
            last_matrix[ptr*40 + i] = data[i];
        }
        ptr = (ptr+1) % 5;

        if (millis()-last_time[ptr] > time_treshold)
            return false;

        for (int pin=0; pin<40 && response; pin++) {
            uint16_t minimum = 1024;
            uint16_t maximum = 1;   // 1 to prevent a division by zero
            for (int r=0; r<history; r++) {
                minimum = min(minimum, last_matrix[r*40 + pin]);
                maximum = max(maximum, last_matrix[r*40 + pin]);
            }
            uint32_t dif = maximum - minimum;
            response &= ((dif*100)/maximum <= relative_treshold) || (dif <= absolute_treshold);
        }

        return response;
    }

    bool is_detected() {
        uint16_t* data = Interface::read_capacity_matrix(16, true);
        bool is_chip_inserted = chip_inserted(data);
        bool is_stable = stable(data);

        return is_chip_inserted && is_stable;
    }

    uint16_t* detect_special_pins() {
        uint16_t* data = Interface::read_capacity_matrix(32);
        uint16_t sorted[40] = {};
        uint32_t average = 0;
        uint8_t count = 0;
        for (int i=0; i<40; i++) {
            if (data[i] > 50) {
                Utils::sort_add(sorted, data[i]);
                average += data[i];
                count++;
            } else if (data[39-i] > 50) {
                low_reset = i;
            }
        }
        average /= count;
        // only the top 5 pins are relevant as power and reset
        static uint16_t tops[5] = {0}; // lower byte indicates pin and higher byte is propability
        for (int t=0; t<5; t++) {
            uint8_t propability;
            uint8_t position;
            if (sorted[t] <= average || sorted[t] <= 25) {
                propability = 0;
            } else {
                propability = (100 * (sorted[t] - average)) / (sorted[0] - average);
            }
            for (int i=0; i<40; i++) {
                if (data[i] == sorted[t]) {
                    position = i;
                    break;
                }
            }
            tops[t] = (propability << 8) + position;
        }
        return tops;
    }

    bool is_ground(pin_t pin) {
        Interface::apply_diode_voltage(pin);
        uint16_t* data = Interface::read_voltage_matrix(64, pin);
        Interface::clear_diode_voltage(pin);
        uint8_t count = 0;
        for (int i=0; i<40; i++) {
            if (data[i] > 100)
                count++;
        }
        return (count >= chip_size - 2 - chip_size/10);
    }

    uint8_t chip_pin(pin_t pin, bool rotate=false) {   // returns pin numbered relatively, to compare with chip numbering
        uint8_t num;
        if (pin < 20) { // right side
            num = (pin - chip_start);
        } else { // left side
            num = (39-pin) - chip_start + chip_size;
        }
        return rotate ? chip_size*2-1 - num : num;
    }

    uint16_t calculate_matching(Chip chip, uint8_t* pins, uint8_t* propabilities, bool* grounds, bool rot=false) {
        if (chip_size*2 != chip.pin_count)
            return 0;
        
        uint16_t propability = 0;
        if (low_reset != 255 && chip.RESET == chip_pin(low_reset, rot)) {
            propability += 100;
        } else if (low_reset == 255) {
            for (int i=0; i<5; i++) {
                if (!grounds[i] && chip.RESET == chip_pin(pins[i], rot))
                    propability += propabilities[i];
            }
        }

        for (int i=0; i<5; i++) {
            if (grounds[i] && (chip.GND[0] == chip_pin(pins[i], rot) || chip.GND[1] == chip_pin(pins[i], rot))) {
                propability += propabilities[i];
            } else if (!grounds[i] && (chip.VCC[0] == chip_pin(pins[i], rot) || chip.VCC[1] == chip_pin(pins[i], rot))) {
                propability += propabilities[i];
            }
        }
        return propability;
    }

    void identify_chip() {
        Chip propable_chip = UnknownChip;
        uint16_t chip_propability = 0;
        uint16_t* special_pins = detect_special_pins();
        uint8_t pins[5] = {0};
        uint8_t propabilities[5]= {0};
        bool grounds[5] = {0};
        for (int i=0; i<5; i++) {
            pins[i] = special_pins[i] & 255;
            propabilities[i] = (special_pins[i] & (255 << 8)) >> 8;
            
            if (propabilities[i] == 0)
                continue;
            grounds[i] = is_ground(pins[i]);
        }

        for (Chip chip : chips) {
            uint16_t propability = calculate_matching(chip, pins, propabilities, grounds);
            if (propability > chip_propability) {
                propable_chip = chip;
                chip_propability = propability;
            }
        }        
        for (Chip chip : chips) {
            uint16_t propability = calculate_matching(chip, pins, propabilities, grounds, true);
            if (propability > chip_propability) {
                rotated = true;
                propable_chip = chip;
                chip_propability = propability;
            }
        }
        detected_chip = propable_chip;
    }
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
